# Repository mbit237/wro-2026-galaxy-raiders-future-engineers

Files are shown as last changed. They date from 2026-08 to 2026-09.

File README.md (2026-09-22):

# WRO Future Engineers 2026 - Galaxy Raiders 

## Content 

- [Team](#Team)

- [Game Rules](#2026-WRO-Future-Engineers-Game-Rules)

- [Hardware documentation](schemes/README.md)

- [Software documentation](src/README.md)

- [Models](models/README.md)

- [Video](video/video.md)

## Team 

- Henry
- Xin Yu
- Joshua

## 2026 WRO Future Engineers Game Rules

Details of the rules and challenge can be found at this link: [2026 WRO Future Engineers Game Rules](https://wro-association.org/wp-content/uploads/WRO-2026-Future-Engineers-Self-Driving-Cars-General-Rules.pdf)

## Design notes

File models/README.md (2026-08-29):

# Modelling Documentation

## The Base

As compared to last year's design, we have reduced the length significantly from 250mm to 160mm by rearranging and modifying the components to be more space efficient. The width of the base plate has also been shrunk from 134mm to 100mm. This has benefitted us greatly as the bot now has a smaller turning radius which makes its turning sharper and more responsive.

### Base Plate

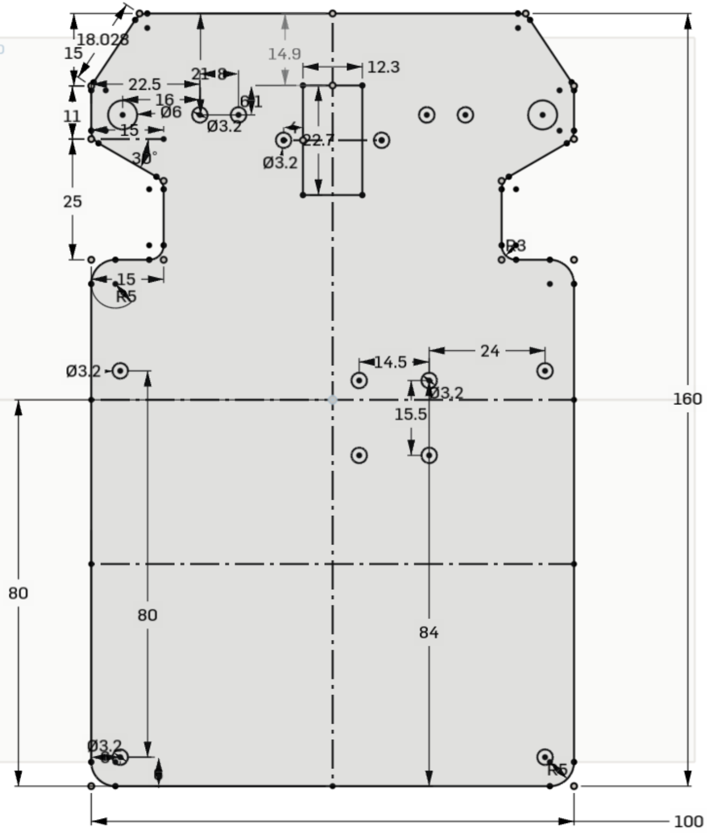
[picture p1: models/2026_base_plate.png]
base_plate


We have rearranged the motor such that it is now parallel to the wheel shaft, allowing the robot to be much shorter than the previous iteration. We also had to redesign the Ackermann steering to accommodate to the change in the base length. There are also corner cuts at the front of the base so that it does not get in the way of the wheels when steering.

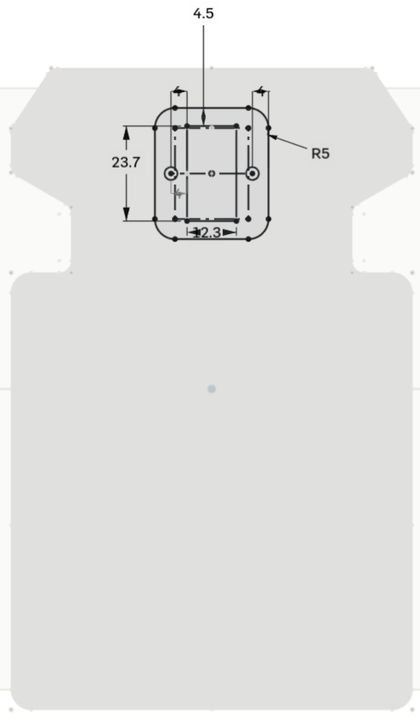
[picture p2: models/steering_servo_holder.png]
steering_servo_holder


This part is designed to sandwich the servo against the base plate, ensuring that the servo motor is secured in position.

### Level Plate

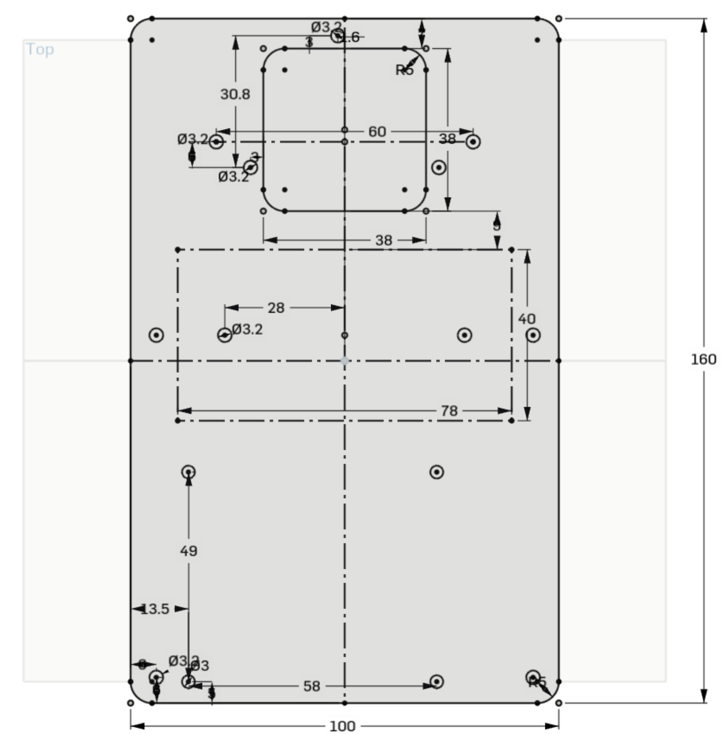
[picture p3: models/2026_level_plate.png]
level_plate


The components on the level plate has also been arranged in a much more compact manner. The main change we have made shrinking the size of the PCB, which had a lot of empty space previously. This was done by shifting the positions of the components of the PCB, reducing the amount of unoccupied space. 

### Ackermann Steering

<table>
  <tr>
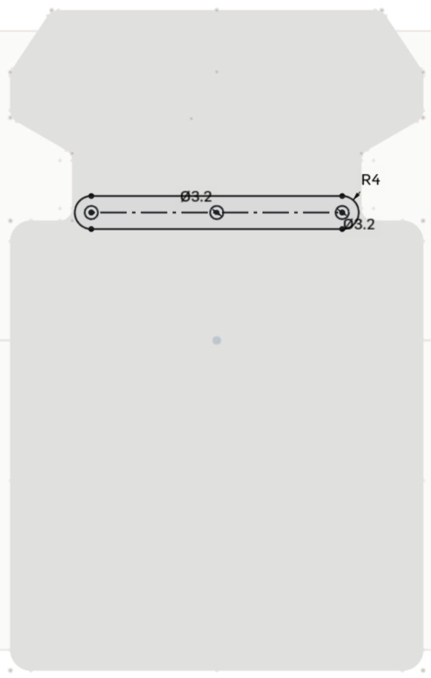
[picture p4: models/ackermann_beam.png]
ackermann_beam
    <td></td>
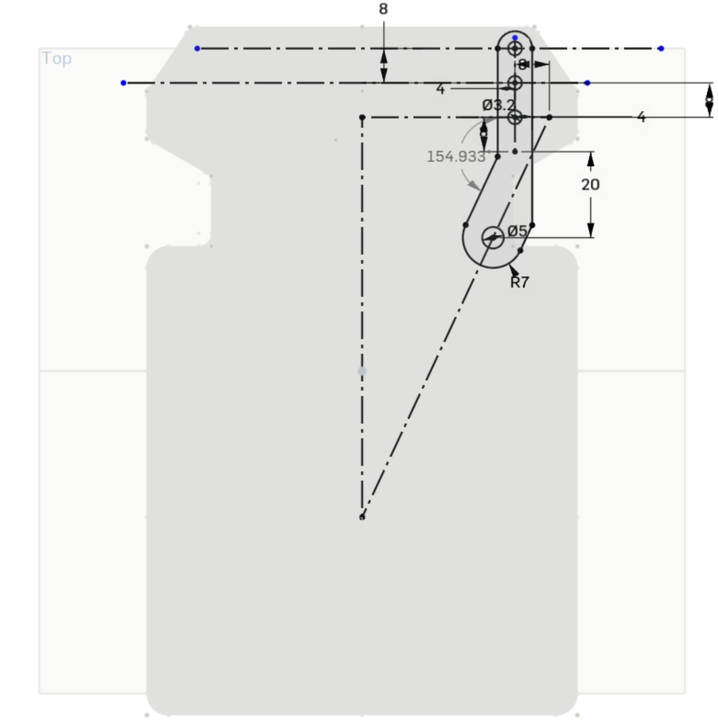
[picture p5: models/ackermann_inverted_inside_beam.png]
ackermann_inverted_inside_beam
    <td></td>
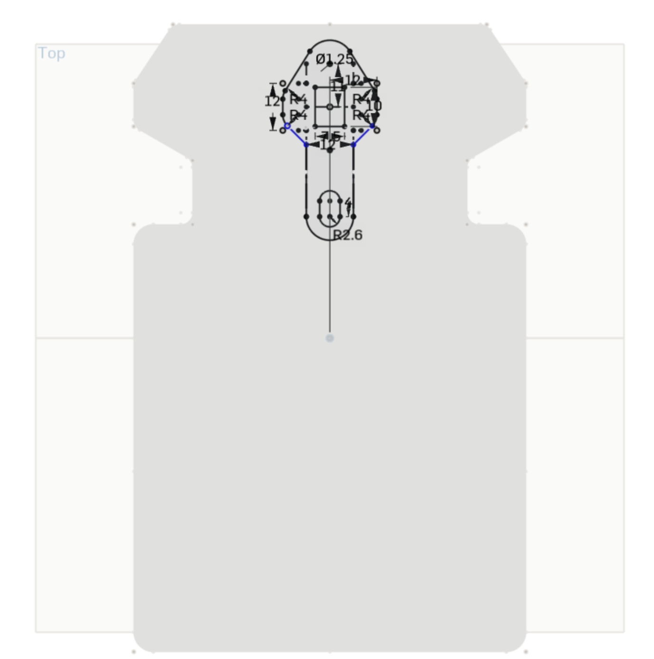
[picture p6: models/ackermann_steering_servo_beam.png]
ackermann_steering_servo_beam
    <td></td>
  </tr>
</table>

<!-- ![ackermann_beam](ackermann_beam.png), [ackermann_inverted_inside_beam](ackermann_inverted_inside_beam.png), [ackermann_steering_servo_beam](ackermann_steering_servo_beam.png) -->

The Ackermann steering mainly uses 3 parts, the steering arms, which are connected to each wheel, a servo beam, which connects to a servo motor driving the mechanismI, and a longer beam linking the steering arms and servo beam together. In order to calculate the dimensions of the Ackermann steering geometry, we sketched it out in the CAD software before laser cutting the parts, ensuring that each component was of the exact dimensions.

### Camera 

<table>
  <tr>
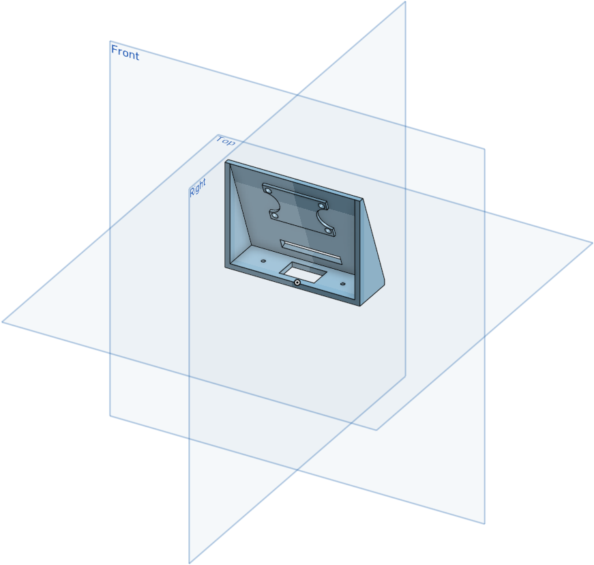
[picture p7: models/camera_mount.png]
ackcamera_mountermann_beam
    <td></td>
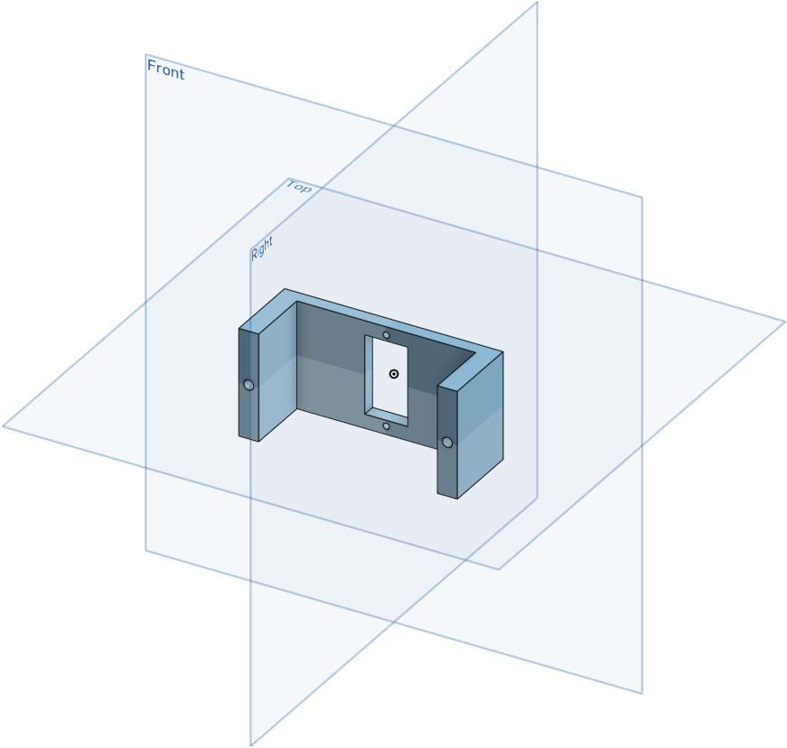
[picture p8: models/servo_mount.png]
servo_mount
    <td></td>
  </tr>
</table>

<!-- ![camera_mount](camera_mount.png), ![servo_mount](servo_mount.png) -->

The current version of our bot features a swiveling camera, which replaces the wide-angle camera found in the previous version. Although the field of view is only 60 degrees, as compared to the 120 degrees of the wide-angle lens, the servo attached to the camera allows it to swivel and face the obstacles, mitigating the problem of not being able to see the obstacle past a certain point.

### Raspbery Pi standoff

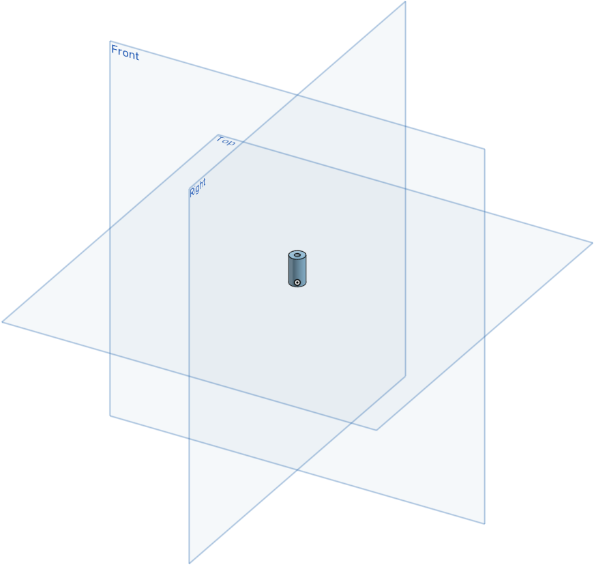
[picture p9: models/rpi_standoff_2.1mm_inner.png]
rpi_standoff


We also 3D printed a standoff to support the PCB as it was connected to the Raspberry Pi in such a way that it would be slighty tilted without the standoff.

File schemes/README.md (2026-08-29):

# Schemes
## Assembly
Our robot consists of 2 layers of components. From the 2025 competition, we continued with the idea of making use of our vertical space to mount all our components. This is achieved by splitting our robot into **different layers**. 
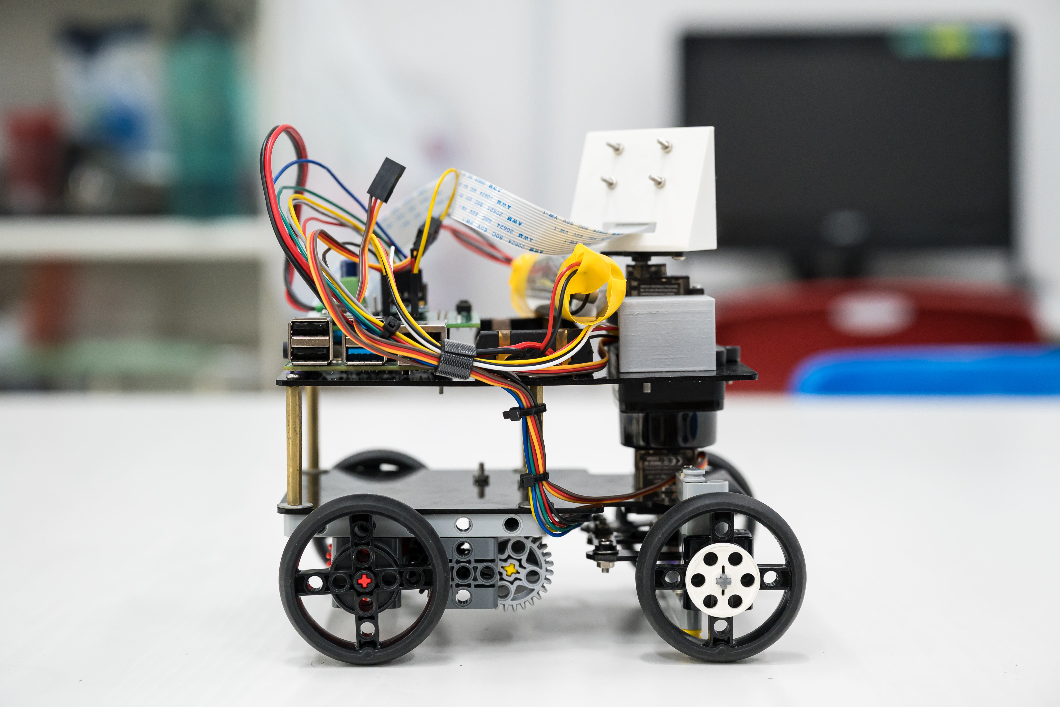
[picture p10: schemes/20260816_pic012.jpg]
robot_side_view


The **underface of the bottom layer** of our robot comprises of all our main drivebase components. This includes our Ackermann Steering Mechanism, and our Rear Wheel Drive mechanism, both of which are explained in more detail under the Mechanical Designs of this README file. The upperface of our bottom layer is not used.
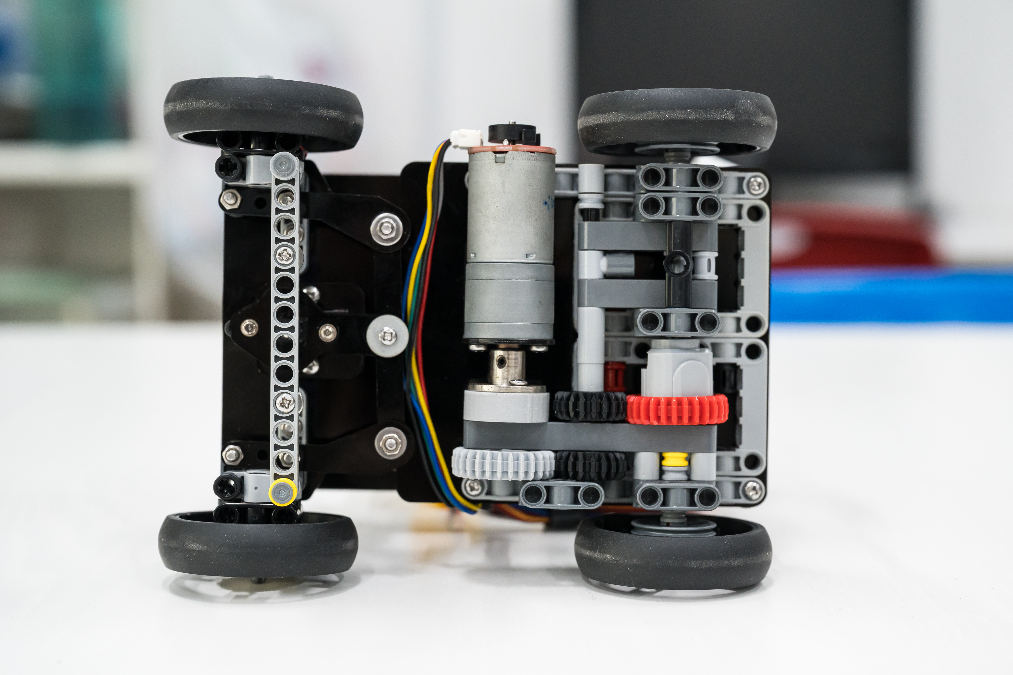
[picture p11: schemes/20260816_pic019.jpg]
robot_bottom_view


On our second/top layer, we utilise both the **underface** and the **upperface** of this layer for our robot components. 

On the **upperface**, we mounted components such as our Raspberry Pi Controller module, our PCB that is directly attached to our Raspberry Pi, a battery holder, and our rotating Camera mount. Mounting these components came with several issues, as there were several considerations when mounting each component. One of the most significant considerations we had to take into account was the importance of balancing our centre of gravity. In terms of our left-right centre of gravity, our drivebase motor on the bottom layer is mounted with a slight offset to the left. As such, we had to mount the components on our top layer to cancel out this offset. 
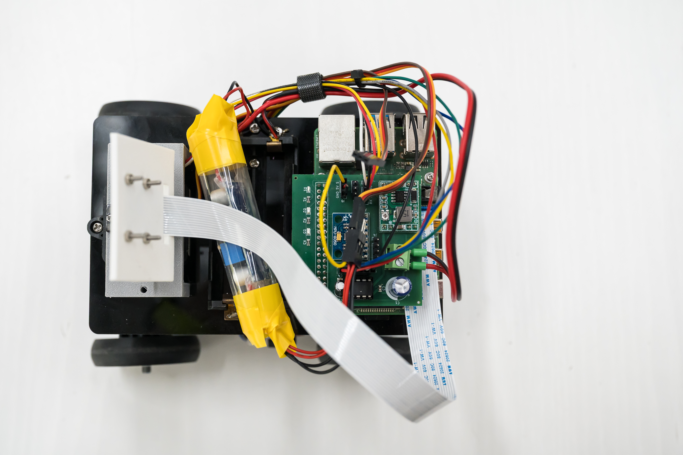
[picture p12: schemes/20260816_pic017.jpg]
robot_top_view


On the **underface of our second/top layer**, is where we mounted our Coin-D4 LiDar sensor. This is because both our layers are connected together by a long standoff, creating a large amount of empty space between both layers that allows the LiDar to capture the most readings. In this way, the only slight blindspots for our LiDar would be in the location and direction of the 4 standoffs connecting the two layers of our robot together. However, these blindspots are insignificant and almost negligible. In addition, with these standoffs in place, it acts as a pillar where we can fasten our long and stray wires to, so as to prevent the wires from being an obstruction to our LiDar and influencing our readings. In particular, the wires from the motor of our drivebase had to be routed upwards to connect to the PCB on the top layer of our robot. 
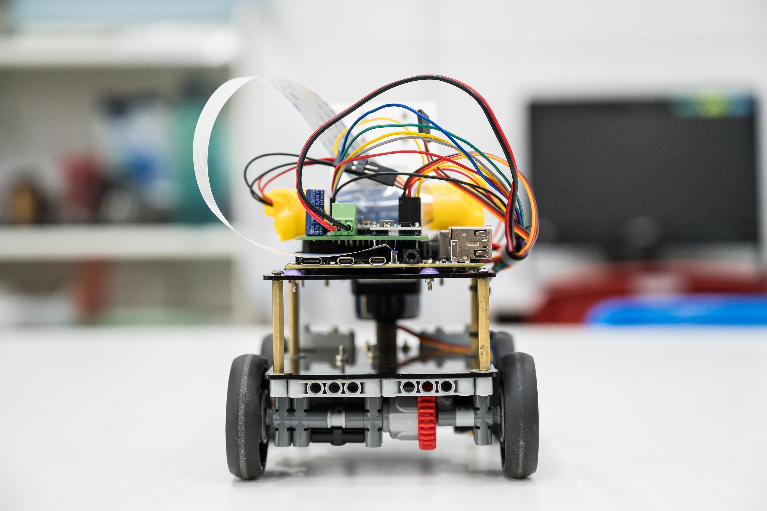
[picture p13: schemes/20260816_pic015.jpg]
robot_back_view


## Sensors
### Lidar
A **Lidar sensor** uses laser beams and speed of light to measure the distance in front of the sensor, and is useful for 2D mapping, as it provides accurate readings/measurements from any angle. The model of the Lidar sensor we are using is the **COIN-D4**, a compact, 360-degree coaxial laser scanner developed by Guoke Optical Core. It provides high-frequency distance measuring between 0.05 to 12 meters. 
CoinD4

### IMU (Gyro)
a **Gyro** allows us to measure rotation around different axes(x, y and z), allowing us to find our direction of rotation and rotation angle for our robot. By using a gyro, we can be more reliable and accurate at measuring rotation over a short period of run time. The Gyro component we are using is the **MPU-6050**, a 6-axis Inertial Measurement Unit (IMU), that combines a 3-axis gyroscope to measure rotational speed or twist, and a 3-axis accelerometer to measure gravity and linear acceleration. The built in I2C protocol allows us to communicate with this IMU sensor through our Raspberry Pi microcontroller. 
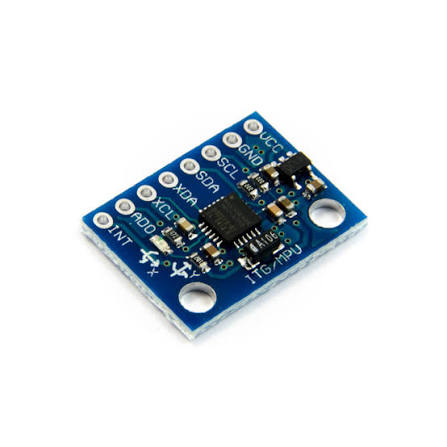
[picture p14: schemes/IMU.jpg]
IMU


### Motor Encoder
A **motor encoder** is a sensor that tracks a motor shaft's rotation and converts it into electrical signals for our Raspberry Pi. Its main purpose is to provide real-time feedback on position, speed, and direction of our drive motor. The Motor Encoder we have used for our robot is an **AB Hall-effect Encoder**, which is a type of quadrature encoder that measures rotation using the strength of the magnetic field in the x and y direction, and measures the positive/negative magnetic charge in those directions. 
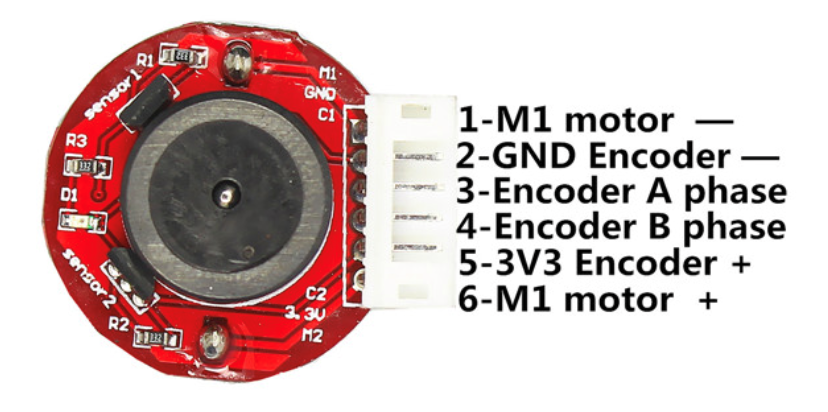
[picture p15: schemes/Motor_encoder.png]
Motor_encoder


### Motor Driver
A **motor driver** serves to regulate, direct, and coordinate the electrical energy supplied to our motor. The motor driver we have implemented on our robot is the **TA6586**, a monolithic, bidirectional H-bridge motor driver IC that uses sign-magnitude drive. In sign-magnitude control, the sign determines the motor's direction, while the magnitude determines how strongly the motor is driven. 

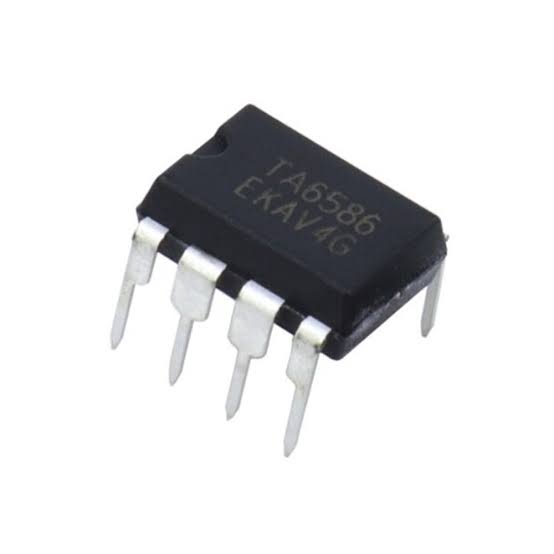
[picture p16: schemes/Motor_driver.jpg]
Motor_driver


### Camera
The **camera** lets us capture real-time footage of the Future Engineer Field while the robot is moving. This camera mainly serves to detect the red and green obstacles, allowing our robot to make the appropriate movement adjustments accordingly. The camera we have used for our robot is the **Raspberry Pi Camera Module v2**, an official 8-megapixel small add-on board with a Sony IMX219 CMOS image sensor, designed to plug directly into the CSI port of our Raspberry Pi.
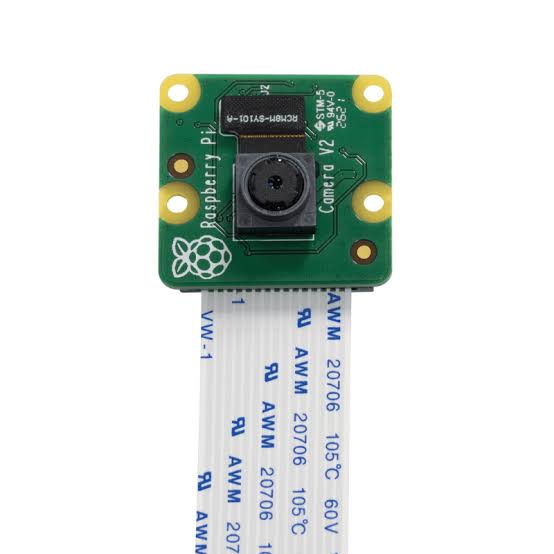
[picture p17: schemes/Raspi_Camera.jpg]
Raspi_Camera


## 3D Printed Parts
For every component that we wanted to design ourselves, we went through the same process for every part. We firstly had to figure out the functionality of said component, followed by the restrictions for the part, including size limitations, surrounding components, etc, before figuring out and taking suitable measurements for the mounting location of the part. 

To see the full designing process of each 3D printed component of our robot, please refer to the README file document in our models folder. 

## Mechanical Designs

### Drive Module
For the driving of our robot, we used a **Rear-Wheel-Drive (RWD) structure**. This structure consists of one motor, driving a central shaft that is linked to the main Differential gear, that drives two shafts on either ends of the gearbox as the outputs. Our wheels are then mounted on both shafts. For our robot in particular, our RWD structure is more unique. Our motor that drives the gearbox is not linked directly to the shaft, but mounted sideways instead to save space. By linking the motor shaft to the gearbox through gears on the side, it allows our RWD to achieve the same results, while reducing the size of our drivebase. 
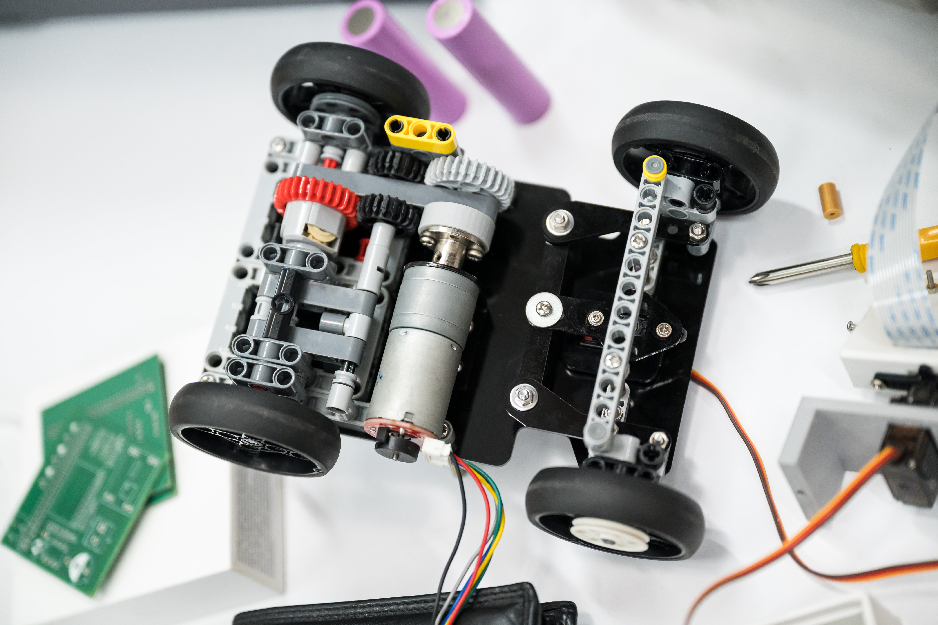
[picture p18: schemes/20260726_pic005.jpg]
drive_base


### Steering
For our steering, we referenced the popular **Ackermann Steering geometry**, that is often used in cars, vehicles etc. The Ackermann Steering geometry consists of a system of linkages on a vehicle's steering that makes the inner front wheel turn at a sharper angle than the outer front wheel in a turn, so that both steering wheels point to a common turning center. This is achieved by designing a custom Ackermann Steering linkage that connects our steering servo motor to our wheel components. To see the full designing process of this Ackermann linkage, do refer to the README file in our models folder.
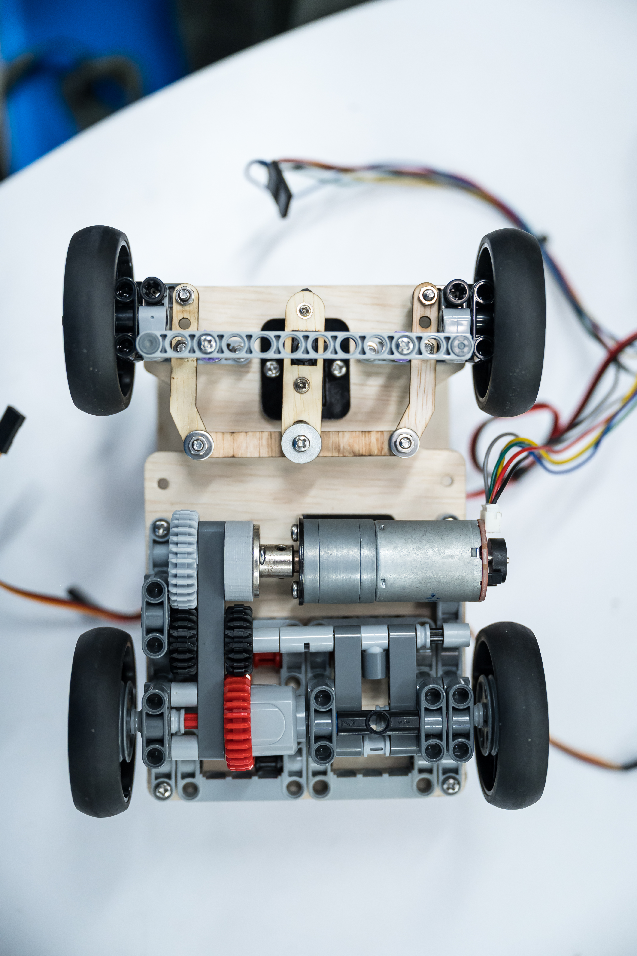
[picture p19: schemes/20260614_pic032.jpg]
Ackermann_Steering


### Camera Rotation
In the 2025 Future Engineers competition, our camera often failed to detect obstacles near the edge of the camera's POV. As such, we wanted to improve our camera mount, instead of just being a fixed stationery mount, to be able to **rotate** and check for obstacles from **different angles** quickly. This mechanism was fairly straightforward and simple, as it merely required us to mount the camera on a servo motor. We achieved this by designing a custom elevation bracket with a rectangular slot in the middle for the servo motor to lie in. This bracket allos the servo motor to sit above our LiDar sensor, a location we found most suitable for our camera. Thereafter, we mounted our Camera bracket to the servo motor, allowing our camera to then rotate within a range of 180 degrees. 

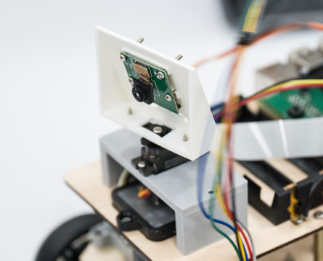
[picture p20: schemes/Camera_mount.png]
Camera_rotation


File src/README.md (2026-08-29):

# Software Documentation 

## General Approach (applied to both open and obstacle challenge)

1. [Odometry](#odometry): Estimating pose using [encoder](#encoder---ab-hall-effect-encoder) and [gyro](#gyro---mpu-6050)
2. [Localisation](#localisation) using LiDAR using [Iterative Closest Points](#iterative-closest-point) (previously [Spike Landmark](#spike-landmark)) before merging both the odometry pose and localised pose using a [complementary filter](#complementary-filter)
3. [Path following](#path-following) using the new merged pose 

## Sensor Libraries 

### LiDAR - COIN-D4 

We created our own library, because there weren't any python raspberrypi libraries, to receive data from the COIN-D4 LiDAR which uses the UART protocol. To create it, we used the serial package to open the serial port /dev/ttyS0 with the baud rate 230400.  

Everytime the input buffer is populated, we check if the first two character matches the data header '\xAA\x55' before retrieving the sample count (4th byte) so that every group of readings is fully taken before being checking the checksum and parsing it. The scan frequency is roughly 10 rotations per second and each frame of data points is 360 degrees.  

Afterwards, each reading is assigned to the closest angle it was taken from, by rounding the angle and taking a modulus of 360 as the index. 

### Gyro - MPU-6050 

The gyro sensor uses the i2c protocol so initially, we used the pigpio library to receive data, but realised it was too slow and caused significant delays, so we switched to smbus. 

Additionally, we had to numerical integrate the z-axis gyroscope data over time to calculate the heading:
1. Read the raw angular velocity
2. Subtract the calibrated gyro offset value
3. Calculate the time passed since the previous reading
4. Take the sum of the current and previous z readings, multiply it by the time passed, and divide it by the sensitivity scale factor (131 * 2)

To find the calibrated gyro offset value, we also created a calibration function so that when we leave the robot as stationary, we can take the average of 500 measurements (which are suppose to be zero values) to find the z error. We also created functions to save the calibration as a txt file and load it. 

### Encoder - AB Hall-effect Encoder 

It is a type of quadrature encoder that measures rotation using the strength of the magnetic field in the x and y direction, and measures the positive/negative magnetic charge in those directionn. The true mechanical angle is then recovered by applying arctangent because the rotating magnet produces orthogonal sine and cosine magnetic field components. 

We used the pigpio library and programmed two callback functions to detect change in states for each channel A (Pin 5) and B (Pin 6)

```python 
cb1 = pi.callback(5, pigpio.RISING_EDGE, self.step_count)
cb2 = pi.callback(6, pigpio.EITHER_EDGE, self.drive_dir)
```

In the first callback, when channel A rises, it checks the state of channel B. If B is high, it is moving backward, whereas if B is low, it is moving in the opposite direction, forward. The second callback is constantly updating the state of channel B. 

Encoder calibration:
2025
1st attempt
- 1522.4mm – 5113 steps, 0.298mm  – 1 step 
2nd attempt
- 4670 mm – 15795 steps, 0.296mm – 1 step

2026
| Actual | Encoder | Time | Notes |
| -----: | ---: | ---: | --- |
| 1285 | 2705 |  5 s | |
| 2005 | 4370 |  8 s | Discarded |
| 2075 | 4365 |  8 s | |
| 2070 | 4357 |  8 s | |

### Motor Driver - TA6586

The TA6586 is a monolithic, bidirectional H-bridge motor driver IC that uses sign-magnitude drive. In sign-magnitude control, the sign determines the motor's direction, while the magnitude determines how strongly the motor is driven. In the library, the sign of the speed argument selects the direction of rotation, while the absolute value of speed determines the PWM duty cycle and by extension the motor speed.

For positive speed, the GPIO pins 20, 21 are configured as such
```python
self.pi.set_PWM_dutycycle(21, 255-speed) # PWM controlled
self.pi.set_PWM_dutycycle(20, 255) # constantly high 
```
vice versa for negative speed
```python
self.pi.set_PWM_dutycycle(21, 255) # constantly high 
self.pi.set_PWM_dutycycle(20, 255+speed) # PWM controlled 
```

This allows for lower switching losses because fewer transistors switch simultaneously 

### Camera - Raspberry Pi Camera Module v2

We use the Raspberry Pi Camera Module with the picamera2 library to identify the colour of the obstacle in front of the car.
The colour detection works as follows:
1. Remove the top 105 pixels from the image to prevent the camera from seeing over the wall, avoiding any false positives
2. Apply a gaussian blur on the image to remove noise and small variations in the image
3. Convert the image from BGR to HSV. HSV is more useful in this case as it separates the hue from the brightness of colours, making it more reliable under different lighting conditions
4. Using cv2.inRange(), a binary mask is applied to the image, where the white parts of the image represent the areas that are within the tested thresholds for green and red obstacles.
5. Run cv2.SimpleBlobDetector() on the binary masks. It rejects blobs that are smaller than 650 pixels to remove any noise

For each colour, detect_blob() will only return the largest blob that it detects.

### Servos (Camera Swivel, Steering) - MG90

To calibrate the servos, we tested with different values from 500 to 2500 microseconds (µs) to find the centre, maximum and minimum. 

| Servo | Centre | Max, Min (in degrees) | 
| -----: | ---: | ---: |
| Camera | 1475 |  87 |
| Steering | 1425 |  42 |

### I/O Interface (Button, LEDs)

In total, we have a button to start and stop the programme and three LEDS (red, yellow, green) to signal different messages for different challenges: open (red -- stationary, green -- running), obstacle (yellow -- stationary, green -- sees green obstacle, red -- sees red obstacle). 

## Localisation 

### Odometry 

We use the wheel rotation and gyro to estimate the robot's pose (position and heading) while it is running. 

- steer_in_dir(): steering (proportional control) 
- augment_path(), augment_paths(): Steering back to line 
    - Find path vector = (x2-x1) / (y2-y1)
    - Find distance of path
    - Find path vector in units
    - Find perpendicular path vector
    - Find path direction 
- dot(): dot product 
    - how far robot is off the path – drive_path()
    - how far robot has traveled along the path 
- drive_path(), drive_paths():

- estimate_pose():
    - First version: looked at the heading and assumed a straight path based on the heading 

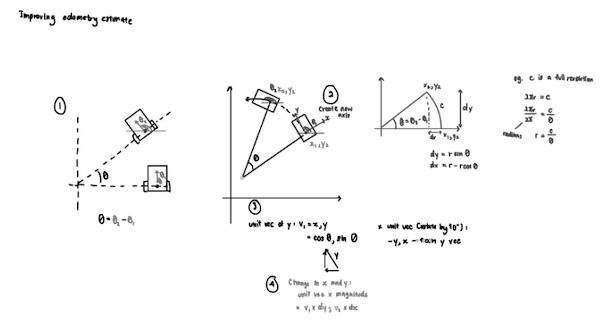
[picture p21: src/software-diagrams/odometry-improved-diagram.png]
odometry-improved-diagram
    

    - Second version: treat the movement as an arc of a circle
        - Treat the centre of rotation as the origin, which means $\theta = \theta_{2} - \theta_{1}$, to find the local $d_x, d_y$
        $$d_y = r sin \theta, d_x = r cos \theta$$
        - Since $r = \frac{c}{\theta}$, in which c is the distance travelled
        $$d_y = \frac{c}{\theta} sin \theta, d_x = \frac{c}{\theta} cos \theta$$
        - To apply this back to the original axis, we take the x, y vectors of the "morphed" graph, (rotate y vector by $90^o$), before we multiply the unit vectors with the local $d_x, d_y$ to find the global $d_x, d_y$
        $$y^′=(cosθ, sinθ)$$
        $$x^′=(−sinθ, cosθ)$$
        $$d_X = x^′ \times d_x, d_Y = y^′ \times d_y$$

Afterwards, we integrate other localisation methods on top of using odometry, by using a complementary filter. 

### Spike Landmark 

Initially, we used the spike landmark method during the 2025 season of WRO, but we wanted to improve our localisation method so we have since shifted to the [Iterative Closest Point](#Iterative-Closest-Point) method. 

Essentially, the method identifies which lidar readings are spikes or points of interest, in our case corners which are noticeably further away than the adjacent readings. Afterwards, we calculate if there is any difference between the supposed and actual cartesian coordinate of the landmark to find the error. 

- Defined 8 landmarks: 4 inner corners, 4 outer corners, marked as green circles
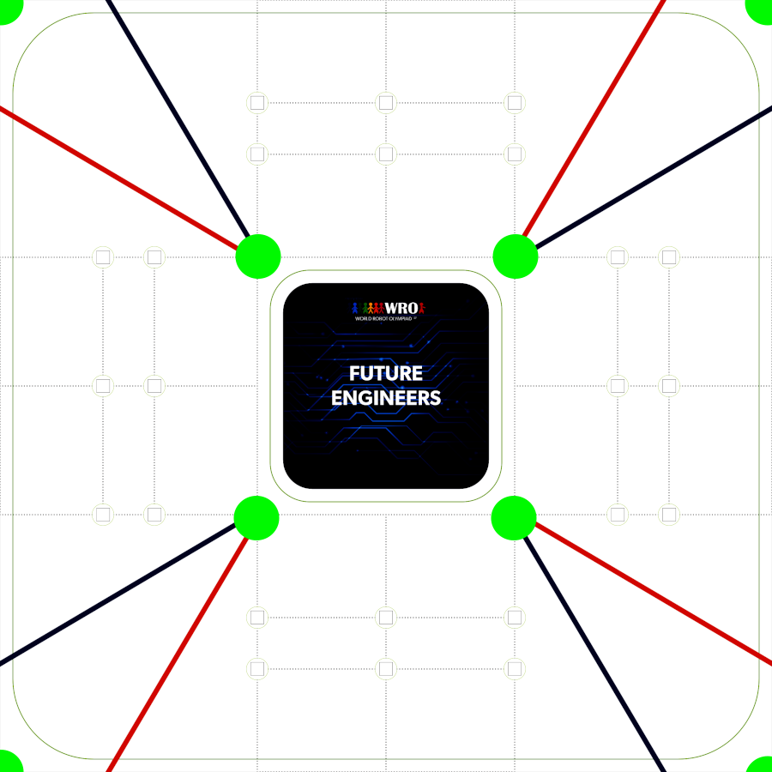
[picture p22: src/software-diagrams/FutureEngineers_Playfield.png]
future-engineers-playfield

- add_cartesian(): convert lidar readings into cartesian coordinates
- identify_spikes()  
	- the different between two lidar measurements adjacent to the centre measurement have to show a significant difference
	- filter out spikes within 250mm
- match_landmarks(): within 120mm, which we tested as the most optimal threshold 
- calc_position_error(), calc_angle_error(): according to the spikes matched, we calculate the total error accumulated for x, y and heading (angle of the spike from the robot) separeately before finding the average for each value and adding it to the odometry_pose 

However, this method only uses a few points out of the approximate 400 we get from the lidar in comparison to the [Iterative Closest Point](#Iterative-Closest-Point) method that makes full use of all the lidar readings. 

### Iterative Closest Point 

- augment_walls(): Define the 8 walls on the playfield, getting their path vector, path direction, unit path vector and perpendicular path vector which are values needed 
- add_cartesians(): same as the one used in the Spike Landmark 

**localise():**
Let's start by transforming 1 point on a cartesian plane. 

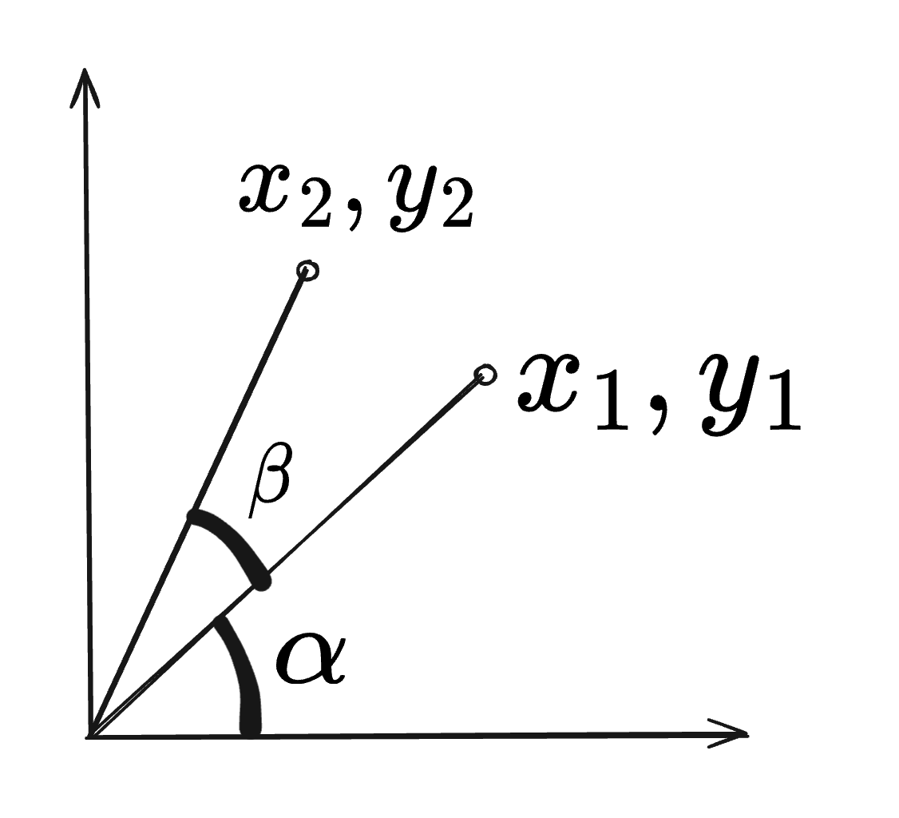
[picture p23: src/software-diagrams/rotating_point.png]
rotating-a-point


To handle the rotation, we can 

$$x_2 = R \cos(\alpha + \beta) = R [\cos(\alpha)\cos(\beta) - \sin(\alpha)\sin(\beta)]$$
$$y_2 = R \sin(\alpha + \beta) = R [\sin(\alpha)\cos(\beta) + \cos(\alpha)\sin(\beta)] $$

Substitute $$x_1 = R \cos(\alpha), y_1 = R \sin(\alpha)$$, 

$$x_2 = x_1\cos(\beta) - y_1\sin(\beta) $$
$$y_2 = y_1\cos(\beta) + x_1\sin(\beta) $$

Since the change in x, y and heading is going to small as the frequency of the Coin-D4 is 10 Hertz, we can linearize the functions, by taking their gradients near 0. 

$$ \cos(\beta) \approx 1, \sin(\beta) \approx \beta $$

$$ \therefore x_2 = x_1 - y_1(\beta), y_2 = y_1 + x_1(\beta) $$

Afterwards, we add translation as $T_x, T_y$

$$ x_2 = x_1 - y_1(\beta) + T_x, y_2 = y_1 + x_1(\beta) + T_y $$
$$ \therefore x_2 - x_1 = -y_1(\beta) + T_x, y_2 - y_1 = x_1(\beta) + T_y $$

When we put it in a matrix form, 

$$ \begin{bmatrix} 
-y_1 & 1 & 0 \\
x_1 & 0 & 1 
\end{bmatrix}
\begin{bmatrix} 
\theta \\
T_x \\
T_y
\end{bmatrix} = \begin{bmatrix} 
x_2 - x_1 \\
y_2 - y_1
\end{bmatrix}
$$

And we can add as many points as we want to the equation

$$ \begin{bmatrix} 
-y_1 & 1 & 0 \\
x_1 & 0 & 1 \\
\vdots & \vdots & \vdots
\end{bmatrix}\begin{bmatrix} 
\theta \\
T_x \\
T_y
\end{bmatrix} = \begin{bmatrix} 
x_2 - x_1 \\
y_2 - y_1 \\
\vdots
\end{bmatrix}
$$ 

To solve this $Ax = B$, we take the psuedoinverse of A multipled by B, $x = A^{-1} B$ which we calculate using the `numpy` library. 

Now that we have the transformation matrix, we need to identify which point on the wall does the lidar reading correspond to, in our case we find the shortest perpendicular distance between each wall and the reading. 

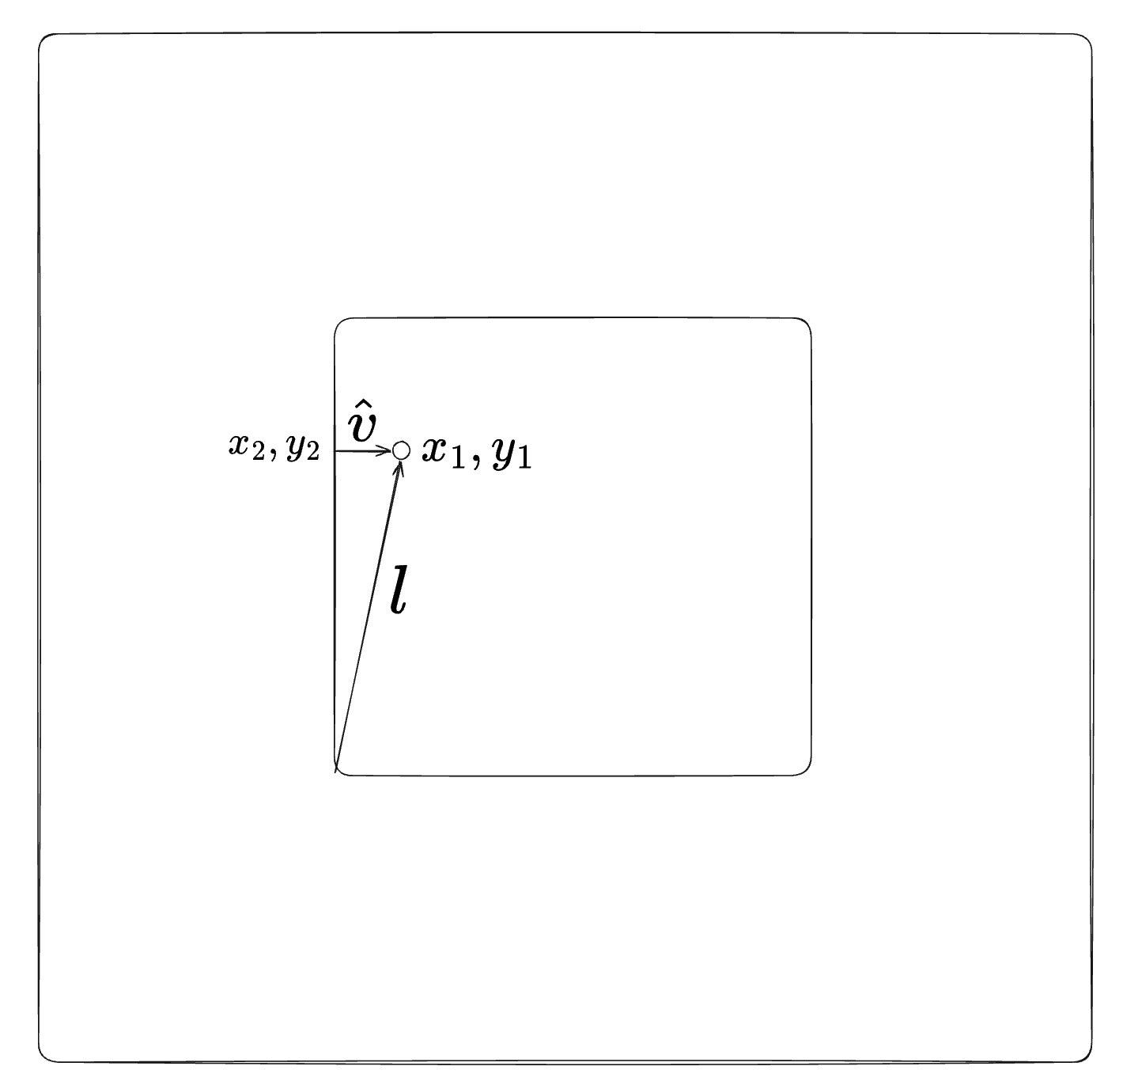
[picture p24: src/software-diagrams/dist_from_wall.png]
dist_from_path


$dist = \hat{v} \cdot l$, in which $l$, is the vector of the lidar reading from the start of the wall. If it is a vertical wall, we only solve for the x-value and vice versa for a horizontal wall. 

**localise_iter():**
Since we are dealing with an overdetermined system, there is no exact solution, but only a rough estimate. Running it with more iterations will help minimise the errors. 

We tested it with a set of fake data which started with the mini-sets contain that have far fewer readings, before moving on to [set 1](/point_cloud_test_sets/set1.txt) which has 360 points, closer to what we will expect in the acutal run. After debugging, we realised that it was able to get close to the actual pose with only one iteration. Additionally, we timed it and it took roughly $\frac{1}{50}$th of a second, meaning it is able to keep up with the lidar which takes 10 readings every 1 second. 

### Complementary Filter

We set very small values for the localisation pose because we found that the odoemetry pose was already quite accurate. 
```
POSITION_FILTER_RATIO = 0.1 
HEADING_FILTER_RATIO = 0.01 
```

## Path following 

pathfollowing

- drive_path(), drive_paths(): 
	- Find the error by taking the dot product of the unit vector perpendicular to the path and the vector from the start of the path to the robot (robot_vector): perpendicular displacement $= \hat{u} \cdot \vec{r} $
	- Get the correction / perpendicular distance of the robot from the path by multiplying the error by a gain
	- Add the target_dir of the path with the correction which is what the robot will steer towards 
	- Keep checking the dist_travelled_along_path if it reaches the end by taking the dot product of the unit_path_vector and the robot vector: displacement along path $= \hat{p} \cdot \vec{r} $

Thus, the robot is able to slowly adjust itself towards the path. 

## Camera Tracking 

- Plotted points along the playfield, in between every pair of squares, where the obstacle could be placed
- Camera will track two points ahead of its current position
- Reused an existing function (dir_to_point) to calculate the angle the servo needs to turn to the obstacle, but adjusting the range to -180 to 180, as the function is used for cases where the range is 0 to 360

### Open Strategy 

During the initialisation, the robot will assume it is moving clockwise and travel the first path until it reaches the corner: this is where the robot will read the distances from lidar sensor for the points (0mm, 2700mm) and (1000mm, 2700mm). If the distance for the left point is greater than the right point, it will deduce that it is moving counterclockwise and update its pose accordingly. The reason why we chose these points instead of measuring the left and right distances is because we encountered some issues with determining the sides at certain start positions.

In the rest of the run, the robot will followed a preplanned clockwise and counterclockwise path, whihc is as close to the centre of the lanes as possible. By default, it would take the outermost path, 50 cm away from the outer wall. However, if the lidar detects that the first section of the inner wall is extended, the lane will shift closer to the wall such that it is 30 cm away from the outer wall. 

We plan on improving our strategy by adjusting the paths to the inner paths where possible. 

**Pseudocode** 

>find initial position 
>first path run to confirm pose
>main run:
>> (process described in [general approach](#general-approach-applied-to-both-open-and-obstacle-challenge))
>> if at ending position:
>>> stop 

### Obstacle Strategy 

The robot will determine its direction (clockwise or counterclockwise) by getting the front, rear and side distances because the initial position generally fixed. It will check if an obstacle is in front of it before moving back. 

In main run, the robot will switch between two fixed sets of paths, an outer and inner lane. Depending on the colour of the blocks in front, it will switch between the two paths to follow. For example, if the robot is moving clockwise, detecting a red block will cause it to follow the inner paths, and vice versa for the green blocks. This will switch if the robot is moving counterclockwise. An improvement we made since 2025 is that we implemented [camera tracking](#camera-tracking) such that the camera follows the colour of the obstacle two sections ahead which ensures that the robot never misses the obstacle. In 2025, a major issue we had is that because our robot was larger and the field of vision of the robot was wider, we had to keep readjusting our paths so that the robot would not miss the obstacles, especially at the corners. 

As of 25th August, the parking programme is still unfinished, but our strategy is to get into the exact position at the start of parking by moving the robot back and forth. As for the parallel parking procedure, it involves 

*(Scenario in which the parking area is on the right)*
- Turn right to 45, move back till vehicle is facing 45
- Turn left to 0, move back till vehicle is behind the barrier 
- Turn left to 45, move back tile vehicle is facing 0 

Reference image:
parallel parking

**Pseudocode**

>find initial position
>if obstacle in front: move back 
>main run:
>> (process described in [general approach](#general-approach-applied-to-both-open-and-obstacle-challenge))
>> if at ending position:
>>> parking

## Debugging / Telemetry tools 

To make it easier to visualise the different variables — robot pose, lidar readings, matched spikes, colour of block detected - we created a telemetry software, using sockets to transfer data from the raspberrypi (client) to a computer (server) with our own protocol. We also kep the messages short so that it all fits in one packet and is not sent too frequently. Afterwards, we used tkinter to draw out the points on the playfield with the exact values written out at the left side of the interface. 

telemetry

Additionally, we changed our intialiser.sh file for easier debugging. Now, every time we run, the programme will log the standard output and error messages to a file with the date and time. To change the mode of the robot (sleep, open, obstacle), we will create a softlink between main_obstacle/open/sleep.py to main.py.

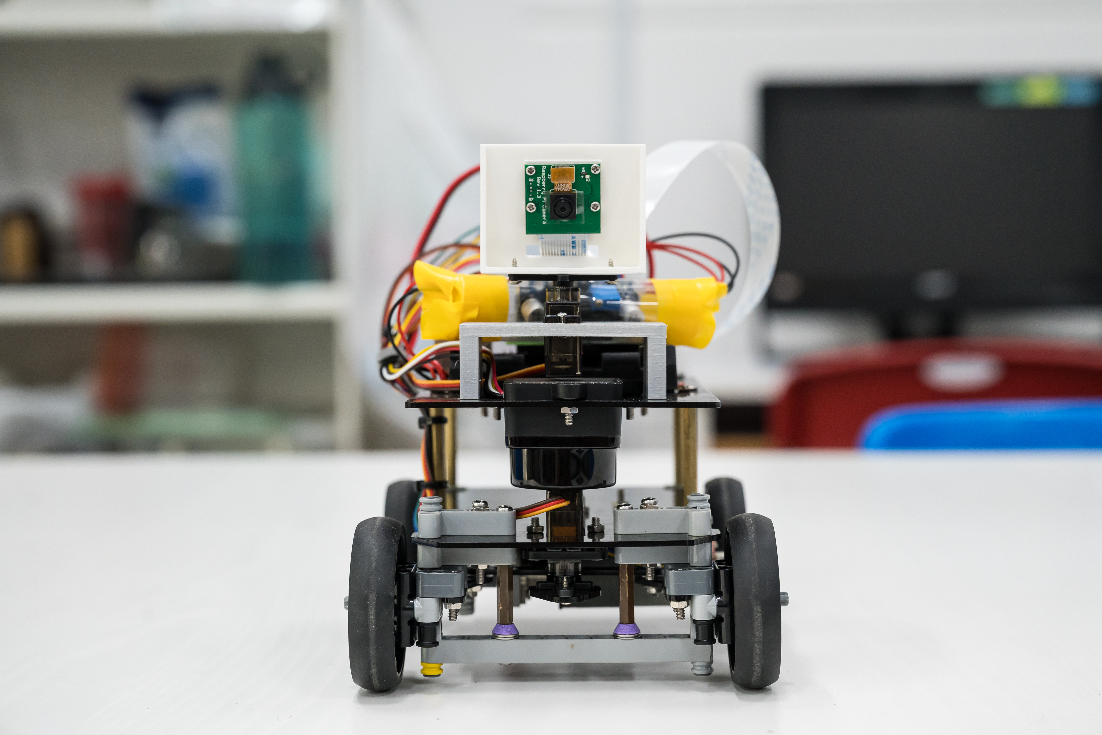
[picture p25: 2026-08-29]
v-photos/20260816_pic013.jpg

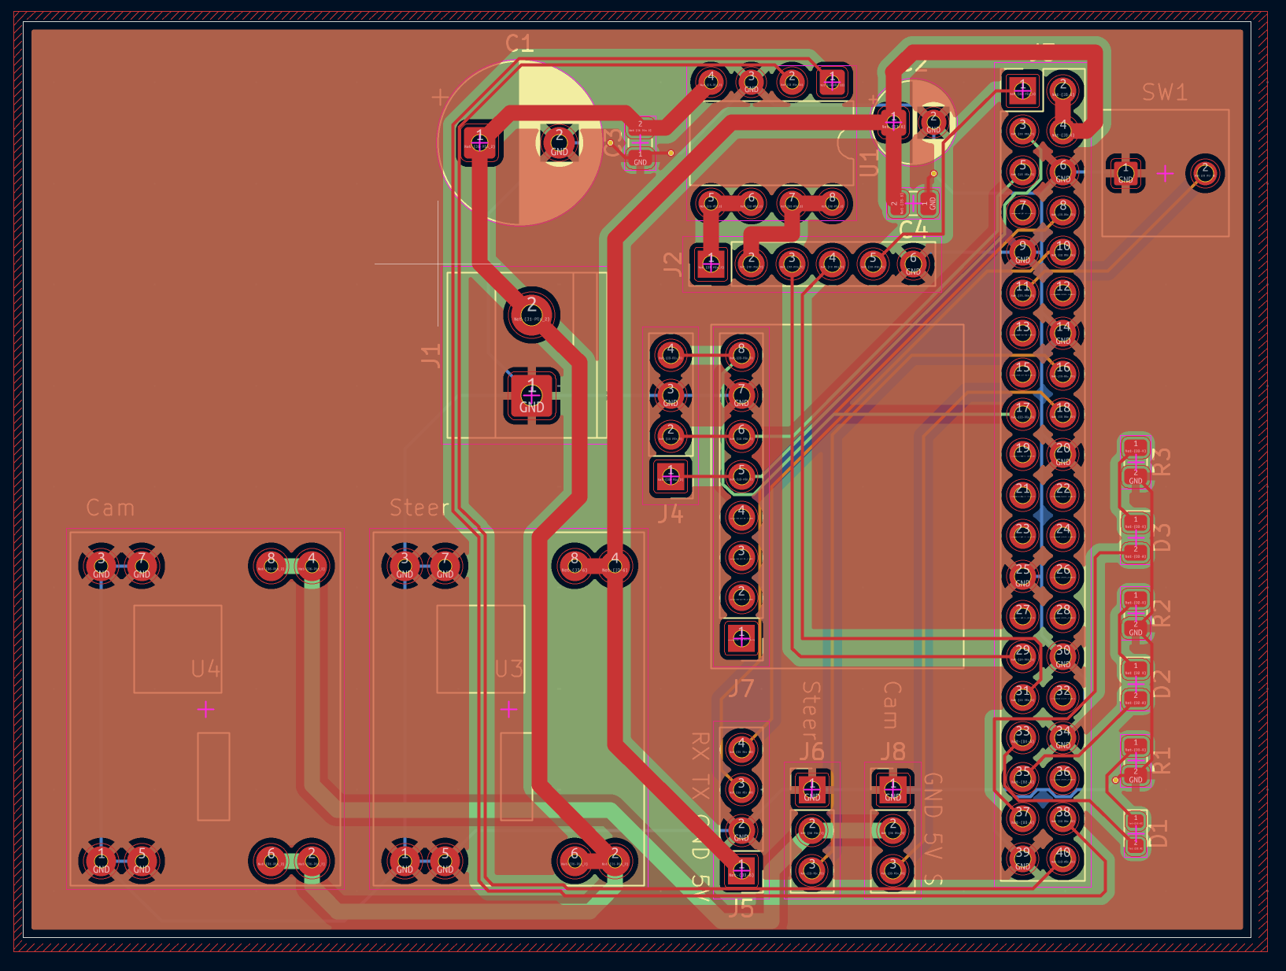
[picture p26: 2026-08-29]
schemes/Screenshot 2026-08-23 at 4.50.41 PM.png

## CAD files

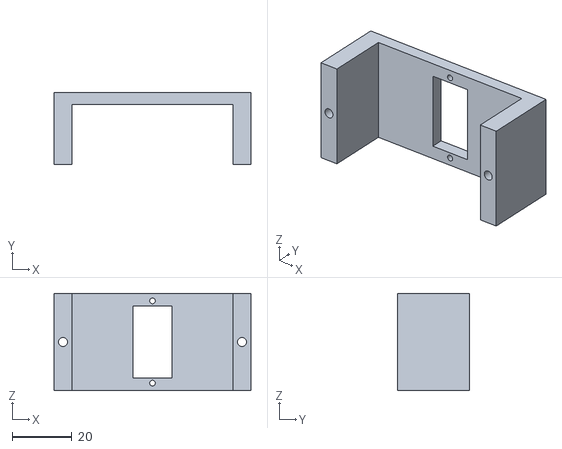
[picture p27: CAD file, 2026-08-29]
models/servo_mount.stl
66.0 x 24.0 x 32.5

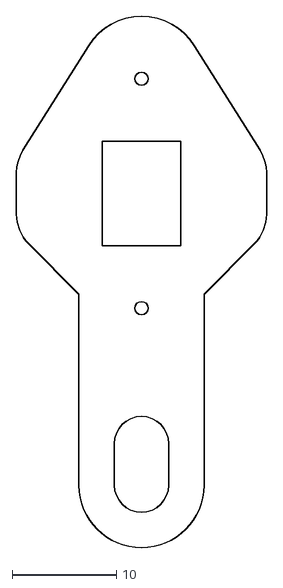
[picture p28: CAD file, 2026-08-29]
models/ackermann_steering_servo_beam.dxf
24.0 x 51.0

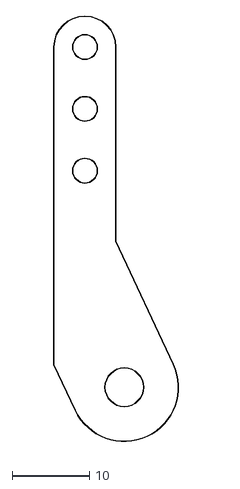
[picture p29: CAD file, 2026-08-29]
models/ackermann_inverted_inside_beam.dxf
17.1 x 56.0

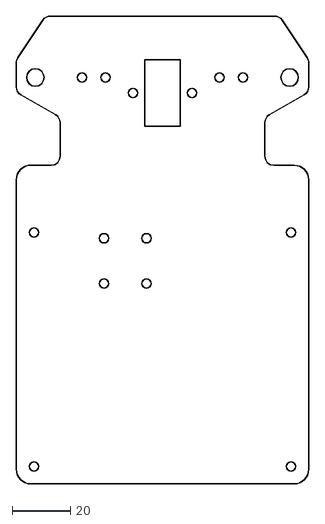
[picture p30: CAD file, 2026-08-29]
models/2026_base_plate.dxf
100.0 x 160.0

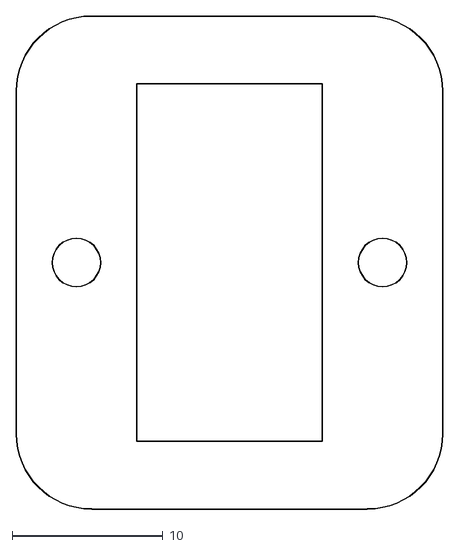
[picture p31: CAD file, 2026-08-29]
models/steering_servo_holder.dxf
28.3 x 32.7

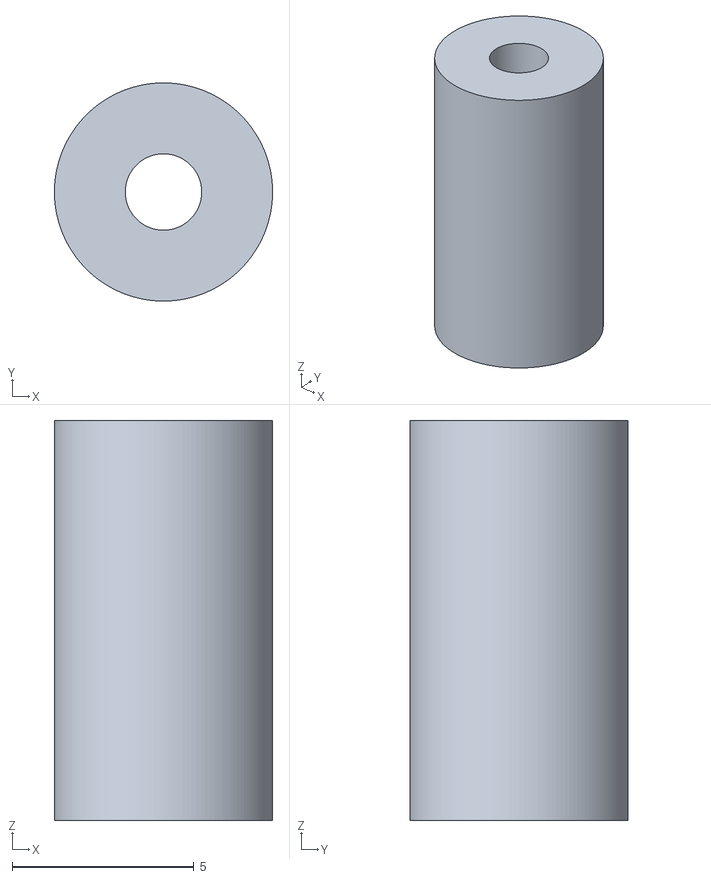
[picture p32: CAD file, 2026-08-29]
models/rpi_standoff_2.1mm_inner.stl
6.00 x 6.00 x 11.0

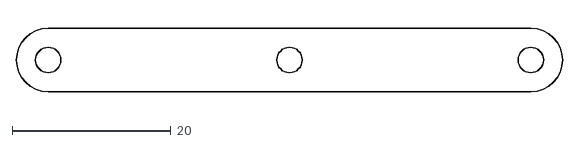
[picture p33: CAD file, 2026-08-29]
models/ackermann_beam.dxf
68.8 x 8.00

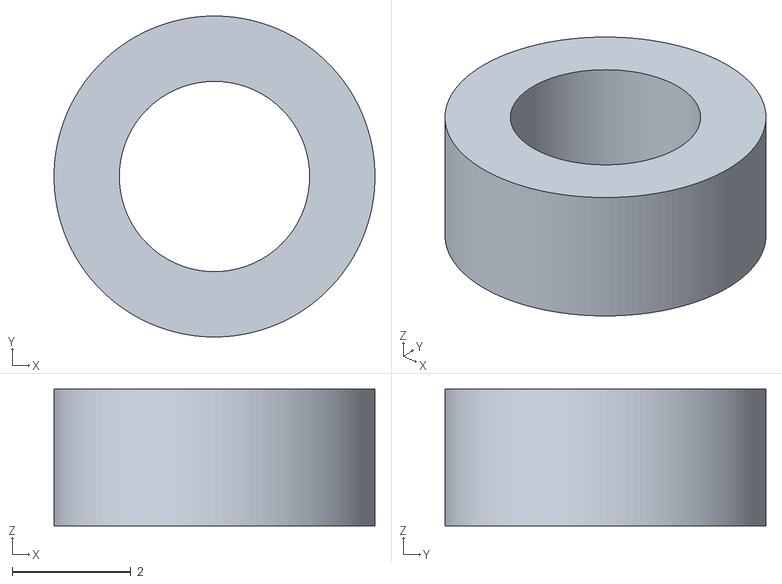
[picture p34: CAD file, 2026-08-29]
models/5.4mm_spacer.stl
5.40 x 5.40 x 2.30

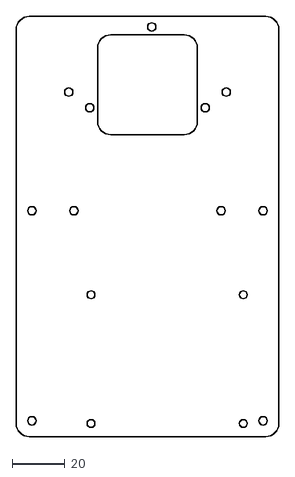
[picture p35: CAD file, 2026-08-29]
models/2026_level_plate.dxf
100.0 x 160.0

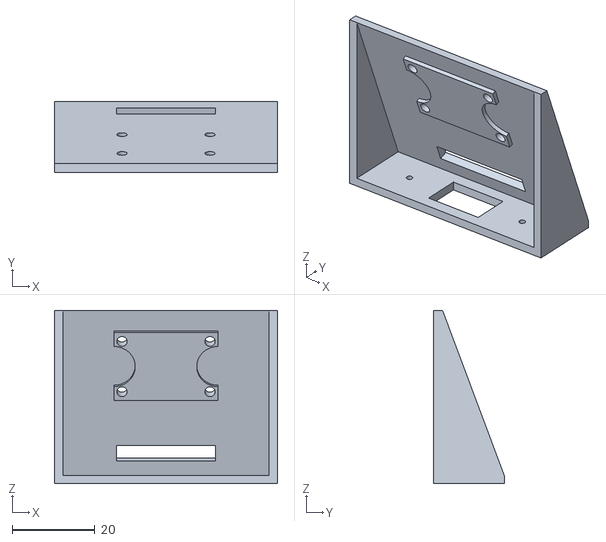
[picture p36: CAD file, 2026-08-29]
models/camera_mount.stl
54.0 x 17.1 x 42.0

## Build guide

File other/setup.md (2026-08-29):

# Setup Guide 

## Transferring files to raspberrypi 

To download all the necessary files into the raspberrypi, use the command:

```bash
scp <path>/<file_name>.py <user>@192.168.0.104:<path>>
```

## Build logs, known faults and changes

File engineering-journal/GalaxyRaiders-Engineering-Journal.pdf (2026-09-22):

# Software Documentation

# General Approach (applied to both open and

# obstacle challenge)

1. Odometry: Estimating pose using encoder and gyro
2. Localisation using LiDAR using Iterative Closest Points (previously Spike Landmark) before merging both the odometry pose and localised pose using a complementary filter
3. Path following using the new merged pose

# Sensor Libraries

## LiDAR - COIN-D4

We created our own library, because there weren't any python raspberrypi libraries, to receive data from the COIN-D4 LiDAR which uses the UART protocol. To create it, we used the serial package to open the serial port /dev/ttyS0 with the baud rate 230400.

Everytime the input buffer is populated, we check if the first two characters match the data header '\xAA\x55' before retrieving the sample count (4th byte) so that every group of readings is fully taken before checking the checksum and parsing it. The scan frequency is roughly 10 rotations per second and each frame of data points is 360 degrees.

Afterwards, each reading is assigned to the closest angle it was taken from, by rounding the angle and taking a modulus of 360 as the index.

## Gyro - MPU-6050

The gyro sensor uses the i2c protocol so initially, we used the pigpio library to receive data, but realised it was too slow and caused significant delays, so we switched to smbus.

Additionally, we had to numerical integrate the z-axis gyroscope data over time to calculate the heading:

- Read the raw angular velocity
- Subtract the calibrated gyro offset value
- Calculate the time passed since the previous reading
- Take the sum of the current and previous z readings, multiply it by the time passed, and divide it by the sensitivity scale factor (131 * 2)
- To find the calibrated gyro offset value, we also created a calibration function so that when we leave the robot as stationary, we can take the average of 500 measurements (which are supposed to be zero values) to find the z error. We also created functions to save the calibration as a txt file and load it.

## Encoder - AB Hall-effect Encoder

It is a type of quadrature encoder that measures rotation using the strength of the magnetic field in the x and y direction, and measures the positive/negative magnetic charge in those directions. The true mechanical angle is then recovered by applying arctangent because the rotating magnet produces orthogonal sine and cosine magnetic field components.

We used the pigpio library and programmed two callback functions to detect change in states for each channel A (Pin 5) and B (Pin 6)

cb1 = pi.callback(5, pigpio.RISING_EDGE, self.step_count)
cb2 = pi.callback(6, pigpio.EITHER_EDGE, self.drive_dir)
In the first callback, when channel A rises, it checks the state of channel B. If B is high, it is moving backward, whereas if B is low, it is moving in the opposite direction, forward. The second callback is constantly updating the state of channel B.

Encoder calibration:
2025
1st attempt: 1522.4mm – 5113 steps, 0.298mm – 1 step 2nd attempt: 4670 mm – 15795 steps, 0.296mm – 1 step

2026

Actual | Encoder | Time | Notes
1285 | 2705 | 5 s

2005 | 4370 | 8 s | Discarded
2075 | 4365 | 8 s
2070 | 4357 | 8 s

## Motor Driver - TA6586

The TA6586 is a monolithic, bidirectional H-bridge motor driver IC that uses sign-magnitude drive. In sign-magnitude control, the sign determines the motor's direction, while the magnitude determines how strongly the motor is driven. In the library, the sign of the speed argument selects the direction of rotation, while the absolute value of speed determines the PWM duty cycle and by extension the motor speed.

For positive speed, the GPIO pins 20, 21 are configured as such

self.pi.set_PWM_dutycycle(21, 255-speed) # PWM controlled self.pi.set_PWM_dutycycle(20, 255) # constantly high
vice versa for negative speed

self.pi.set_PWM_dutycycle(21, 255) # constantly high
self.pi.set_PWM_dutycycle(20, 255+speed) # PWM controlled
This allows for lower switching losses because fewer transistors switch simultaneously

## Camera - Raspberry Pi Camera Module v2

We use the Raspberry Pi Camera Module with the picamera2 and cv2 library to identify the colour of the obstacles in front of the cars.
The colour detection works as follows:
1. Remove the top 105 pixels from the image to prevent the camera from seeing over the wall, avoiding any false positives.
2. Apply a gaussian blur on the image to remove noise and small variations in the image.
3. Convert the image from BGR to HSV. HSV is more useful in this case as it separates the hue from the brightness of colours, making it more reliable under different lighting conditions.
4. Using cv2.inRange(), a binary mask is applied to the image, where the white parts of the image represent the areas that are within the tested thresholds for the green and red obstacles

5. Run cv2.SimpleBlobDetecctor() on the binary masks. It rejects blobs that are smaller than 650 pixels to remove any noise
For each colour detect_blobs() will only return the largest blob that is detected.

## Servos (Camera Swivel, Steering) - MG90

To calibrate the servos, we tested with different values from 500 to 2500 microseconds (µs) to find the centre, maximum and minimum.

Servo | Centre Max, Min (in degrees)
Camera | 1475 87
Steering | 1425 42

## I/O Interface (Button, LEDs)

In total, we have a button to start and stop the programme and three LEDS (red, yellow, green) to signal different messages for different challenges: open (red -- stationary, green -- running), obstacle (yellow -- stationary, green -- sees green obstacle, red -- sees red obstacle).

# Odometry

We use the wheel rotation and gyro to estimate the robot's pose (position and heading) while it is running.
- steer_in_dir(): steering (proportional control)
- augment_path(), augment_paths(): Steering back to line
| ○ Find path vector = (x2-x1) / (y2-y1)
| ○ Find distance of path
| ○ Find path vector in units
| ○ Find perpendicular path vector
| ○ Find path direction
- dot(): dot product
| ○ how far robot is off the path – drive_path()
| ○ how far robot has traveled along the path
- drive_path(), drive_paths():
- estimate_pose():
| ○ First version: looked at the heading and assumed a straight path based on the
| heading
| ○ Second version: treat the movement as an arc of a circle

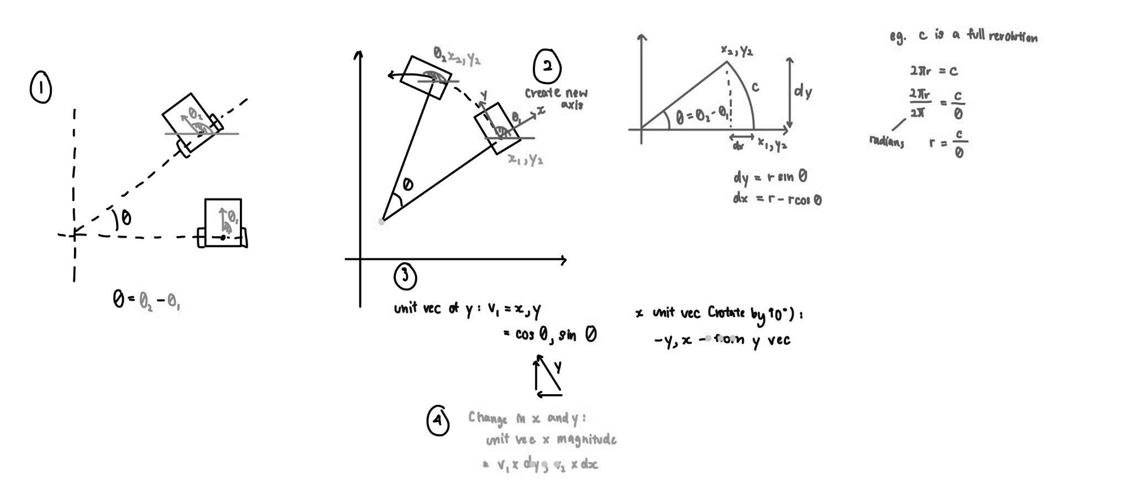
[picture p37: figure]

First, we take the centre of rotation as the origin, which means

θ = θ

2 − θ
1

d

y = rsinθ, d

x = rcosθ

r =

c
θ
in which c is the distance travelled

d

y =

c
θ

sinθ, d

x =

c
θ

cosθ

To apply this back to the original axis, we take the x, y vectors of the "morphed" graph, (rotate y

vector by 90 ), before we multiply the unit vectors with the local dx, dy to find the global dx, dy

o

y′ = (cosθ, sinθ)

x

′ = (− sinθ, cosθ)

d

X = x′ × d
x

, d

Y = y′ × d
y

Afterwards, we integrate other localisation methods on top of using odometry, by using a complementary filter.

# Localisation

## Spike Landmark (Old)

Initially, we used the spike landmark method during the 2025 season of WRO, but we wanted to improve our localisation method so we have since shifted to the Iterative Closest Point method.
Essentially, the method identifies which lidar readings are spikes or points of interest, in our case corners which are noticeably further away than the adjacent readings. Afterwards, we calculate if there is any difference between the supposed and actual cartesian coordinate of the landmark to find the error.
- Defined 8 landmarks: 4 inner corners, 4 outer corners, marked as green circles

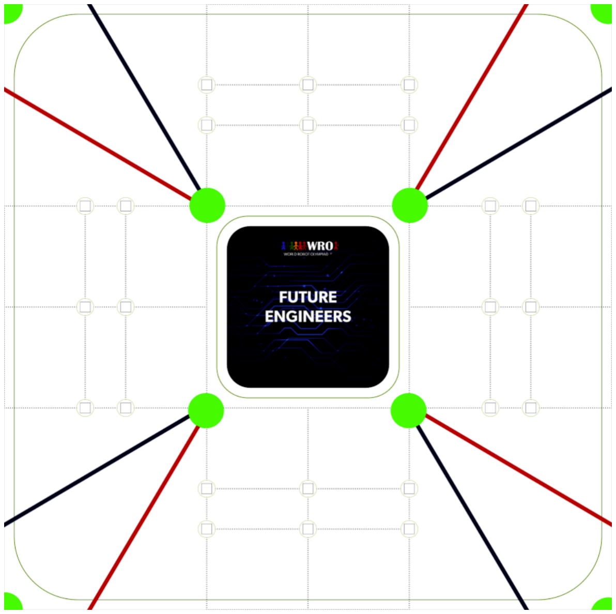
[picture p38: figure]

- add_cartesian(): convert lidar readings into cartesian coordinates
- identify_spikes()
- the different between two lidar measurements adjacent to the centre measurement have to show a significant difference
- filter out spikes within 250mm

- match_landmarks(): within 120mm, which we tested as the most optimal threshold
- calc_position_error(), calc_angle_error(): according to the spikes matched, we calculate the total error accumulated for x, y and heading (angle of the spike from the robot) separately before finding the average for each value and adding it to the odometry_pose
However, this method only uses a few points out of the approximate 400 we get from the lidar in comparison to the Iterative Closest Point method that makes full use of all the lidar readings.

## Iterative Closest Point (current)

- augment_walls(): Define the 8 walls on the playfield, getting their path vector, path direction, unit path vector and perpendicular path vector which are values needed
- add_cartesians(): same as the one used in the Spike Landmark
localise(): Let's start by transforming 1 point on a cartesian plane.
To handle the rotation, we can
Substitute | ,

Since the change in x, y and heading is going to be small as the frequency of the Coin-D4 is 10 Hertz, we can linearize the functions, by taking their gradients near 0.

Afterwards, we add translation as Tx, Ty

When we put it in a matrix form,

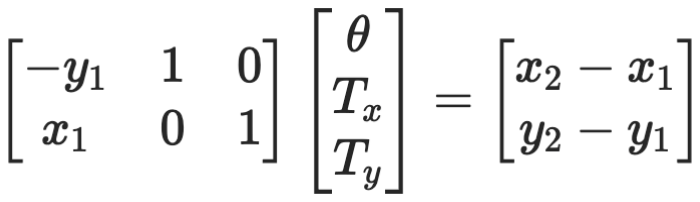
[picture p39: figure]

And we can add as many points as we want to the equation

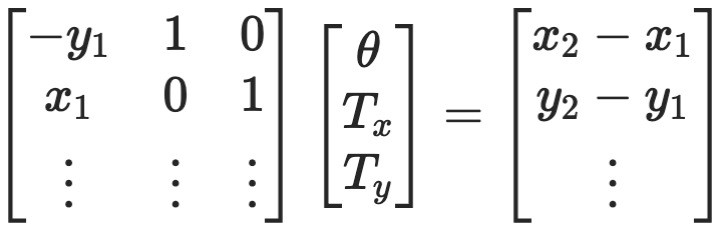
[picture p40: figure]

To solve this Ax = B, we take the pseudoinverse of A multiplied by B, which we calculate using the numpy library.
Now that we have the transformation matrix, we need to identify which point on the wall does the lidar reading correspond to, in our case we find the shortest perpendicular distance between each wall and the reading.

l is the vector of the lidar reading from the start of the wall: if it is a vertical wall, we only solve for the x-value and vice versa for a horizontal wall.
localise_iter(): Since we are dealing with an overdetermined system, there is no exact solution, but only a rough estimate. Running it with more iterations will help minimise the errors.

We tested it with a set of fake data which started with the mini-sets that have far fewer readings, before moving on to set 1 which has 360 points, closer to what we will expect in the actual run. After debugging, we realised that it was able to get close to the actual pose with only one iteration. Additionally, we timed it and it took roughly 1/50th of a second, meaning it is able to keep up with the lidar which takes 10 readings every 1 second.

# Complementary Filter

We set very small percentages for the localisation pose because we found that the odometry pose was already quite accurate.
POSITION_FILTER_RATIO = 0.1
HEADING_FILTER_RATIO = 0.01

# Camera Tracking

- Plotted points along the playfield, in between every pair of squares, where the obstacle could be placed
- Camera will track two points ahead of its current position
- Reused an existing function (dir_to_point) to calculate the angle the servo needs to turn to the obstacle, but adjusting the range to -180 to 180, as the function is used for cases where the range is 0 to 360

# Path following

- drive_path(), drive_paths():
- Find the error by taking the dot product of the unit vector perpendicular to the path and the vector from the start of the path to the robot (robot_vector):

perpendicular displacement = u

^
- r

→

- Get the correction / perpendicular distance of the robot from the path by multiplying the error by a gain
- Add the target_dir of the path with the correction which is what the robot will steer towards
- Keep checking the dist_travelled_along_path if it reaches the end by taking the dot product of the unit_path_vector and the robot vector: displacement along

path = p

^
- r

→

# Open Strategy

During the initialisation, the robot will assume it is moving clockwise and travel the first path until it reaches the corner: this is where the robot will read the distances from the lidar sensor for the points (0mm, 2700mm) and (1000mm, 2700mm). If the distance for the left point is greater than the right point, it will deduce that it is moving counterclockwise and update its pose accordingly. The reason why we chose these points instead of measuring the left and right distances is because we encountered some issues with determining the sides at certain start positions.

In the rest of the run, the robot will follow a preplanned clockwise and counterclockwise path, which is as close to the centre of the lanes as possible. By default, it would take the outermost path, 50 cm away from the outer wall. However, if the lidar detects that the first section of the inner wall is extended, the lane will shift closer to the wall such that it is 30 cm away from the outer wall.

We plan on improving our strategy by adjusting the paths to the inner paths where possible.

Pseudocode:

find initial position
first path run to confirm pose
main run:
(process described in general approach) if at ending position:
stop

# Obstacle Strategy

The robot will determine its direction (clockwise or counterclockwise) by getting the front, rear and side distances because the initial position is generally fixed. It will check if an obstacle is in front of it before moving back.

In the main run, the robot will switch between two fixed sets of paths, an outer and inner lane. Depending on the colour of the blocks in front, it will switch between the two paths to follow.

For example, if the robot is moving clockwise, detecting a red block will cause it to follow the inner paths, and vice versa for the green blocks. This will switch if the robot is moving counterclockwise. An improvement we made since 2025 is that we implemented camera tracking such that the camera follows the colour of the obstacle two sections ahead which ensures that the robot never misses the obstacle. In 2025, a major issue we had is that because our robot was larger and the field of vision of the robot was wider, we had to keep readjusting our paths so that the robot would not miss the obstacles, especially at the corners.

As of 25th August, the parking programme is still unfinished, but our strategy is to get into the exact position at the start of parking by moving the robot back and forth. As for the parallel parking procedure, it involves

(Scenario in which the parking area is on the right)

- Turn right to 45, move back till vehicle is facing 45
- Turn left to 0, move back till vehicle is behind the barrier
- Turn left to 45, move back tile vehicle is facing 0

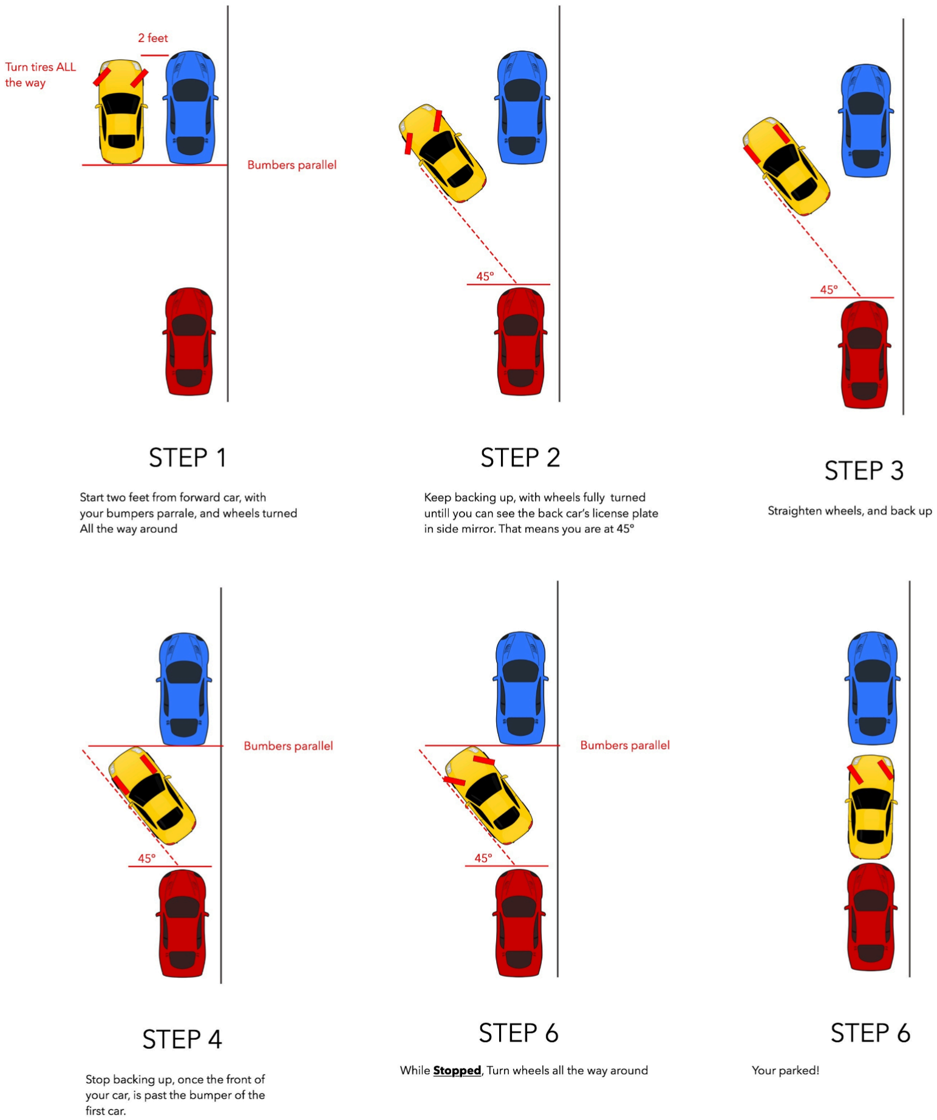
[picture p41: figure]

Pseudocode

find initial position
if obstacle in front: move back
main run:
(process described in general approach) if at ending position:
Parking

# Debugging / Telemetry tools

To make it easier to visualise the different variables — robot pose, lidar readings, matched spikes, colour of block detected - we created a telemetry software, using sockets to transfer data from the raspberrypi (client) to a computer (server) with our own protocol. We also keep the messages short so that it all fits in one packet and is not sent too frequently. Afterwards, we used tkinter to draw out the points on the playfield with the exact values written out at the left side of the interface.

Additionally, we changed our intialiser.sh file for easier debugging. Now, every time we run, the programme will log the standard output and error messages to a file with the date and time. To change the mode of the robot (sleep, open, obstacle), we will create a softlink between main_obstacle/open/sleep.py to main.py.

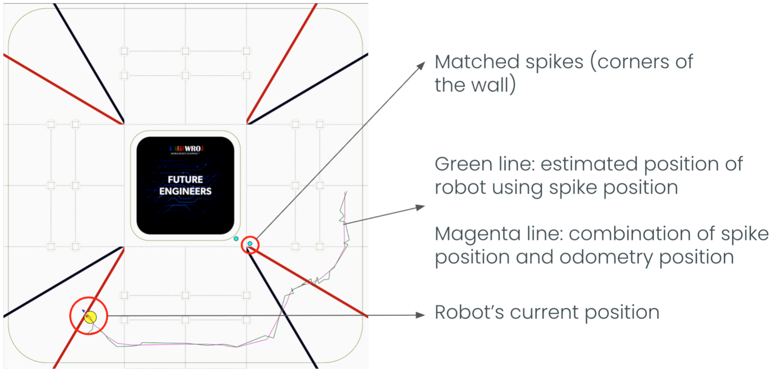
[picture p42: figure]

# Hardware Documentation

After a long break from WRO Internationals 2025, we decided to come back to the studio and start work on our next robot for Future Engineers 2026. While our 2025 FE robot was commendable, it had multiple flaws that needed fixing. Upon starting our preparation, we always fix the mechanical issues first, before moving on to improving our code for the robot itself. As such, we came together and formed a list of flaws that our previous robot had.
- Large robot base - in turn causing a wide turning radius
- Led to many near-miss instances of the robot and the obstacles during our obstacle challenge runs in the competition
- Servo motor for our steering mechanism was not centred
- To adapt to this issue, we initially cut a slot in our steering component for the parts to have more slack when turning, making it smoother
- However, this slack in the parts also caused the steering mechanism itself to be quite unsturdy and loose, which could sometimes lead to inaccurate turns in our robot runs
- Steering wheel components were loose - attached only by the pivot point, and nowhere else
- Because of the singular mounting point, the steering wheel segments often started to bend outwards, due to the force being applied downwards on the base because of our electronic components on the top plate of the robot
- As the steering wheels bend outwards, steering starts to become less smooth, and turning radius is also slightly affected
- Even worse, our steering wheels would sometimes come out due to this looseness issue
- However, this looseness did provide a small amount of suspension for our robot, which allowed it to have more grip on uneven surfaces (at times when the field can get slightly offset)
- Camera was fixed in one direction - entire robot had to turn to allow the camera to see obstacles on the far end of its POV
- Despite using a wide angle lens for our camera last year, it was often not wide enough to detect obstacles at the far end, which may sometimes not appear in the camera’s POV
- Results in making incorrect movements to avoid the obstacles, losing points for our competition runs

After forming this list of main issues, we decided to tackle these issues one by one, throughout a few studio sessions.

# Reducing robot base size

The first issue we fixed was the large robot base. This problem arguably had the most significant impact on our performance, as it was the lead contributor to our failed runs last year. Because of this significance, this issue also came with major changes that had to be done to our robot. This is because simply shrinking our robot frame was not as easy as it seemed; we would need to make our drive base + our Ackermann Steering segment significantly more compact, as well as shrink the layout of our electronic components on the top plate. This process would last a few sessions, but we mainly focused on shrinking the drive base this session.

Initially, our drive base motor, driving the entire RWD module, was mounted perpendicular to the RWD module itself.

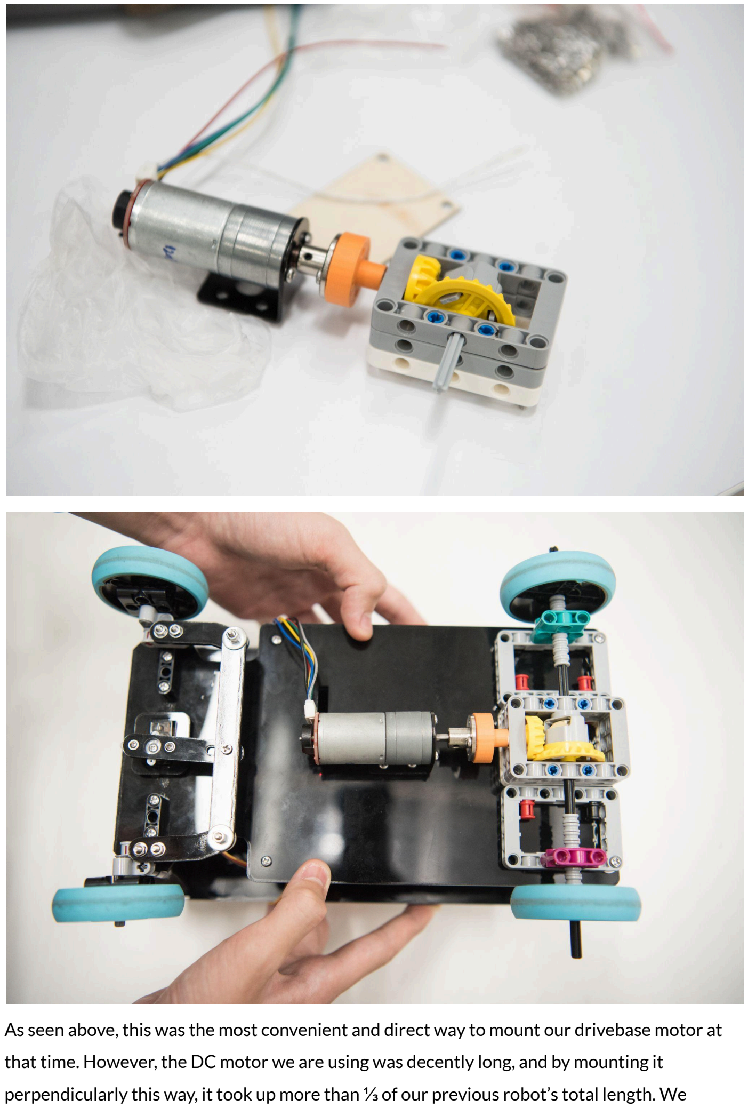
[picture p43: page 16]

As seen above, this was the most convenient and direct way to mount our drivebase motor at that time. However, the DC motor we are using was decently long, and by mounting it perpendicularly this way, it took up more than ⅓ of our previous robot’s total length. We realised that if we wanted to make our robot smaller and more compact, we would need to mount this DC motor in another way.

As such, we started to take apart our previous RWD module, and start from scratch again.

After significantly reducing the size of the RWD module, we still had to similarly reduce the size of our Ackermann Steering module in the front of the base plate, so that we could then reduce the size of the entire base plate. Initially, our steering module was not designed to be compact, as it was our first ever iteration. However, in last year’s competition, because of how wide our turning radius was, the robot often struggled to avoid the obstacles during its runs. The solution to this came in two parts; one was to shorten the length of our robot, reducing the distance between our front and back wheels; and the other was to reduce the distance between our steering wheels, to make our steering angle sharper.

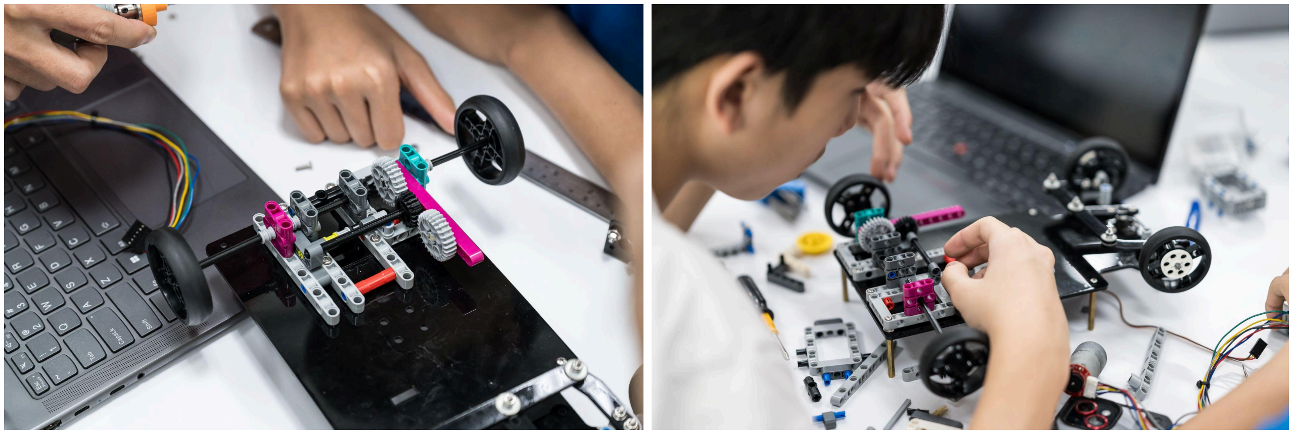
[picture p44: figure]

Over multiple prototypes and a tedious process of trial and error, we eventually built a suitable RWD module that was much more compact than the previous iteration. This was mainly achieved by mounting our DC motor parallel to the RWD module, instead of perpendicular. This cut approximately 8-9cm from the total length of our robot base, a significant cut from our previous robot.

However, mounting the DC motor in a parallel orientation came with a few issues, mainly because the motor would either be too close or too far to the rotating differential gear and shaft. The solution that we eventually found was to gear the DC motor shaft to our main RWD module shaft. This ensured our motor was mounted in an optimal position, while also slightly increasing the speed of our drive base due to the gear ratio of the shafts.

In addition, there was a lot of useless space taken up by our wheel shafts that could be cut from both sides to reduce the width of our robot. After all these changes, our new RWD module looked like this:

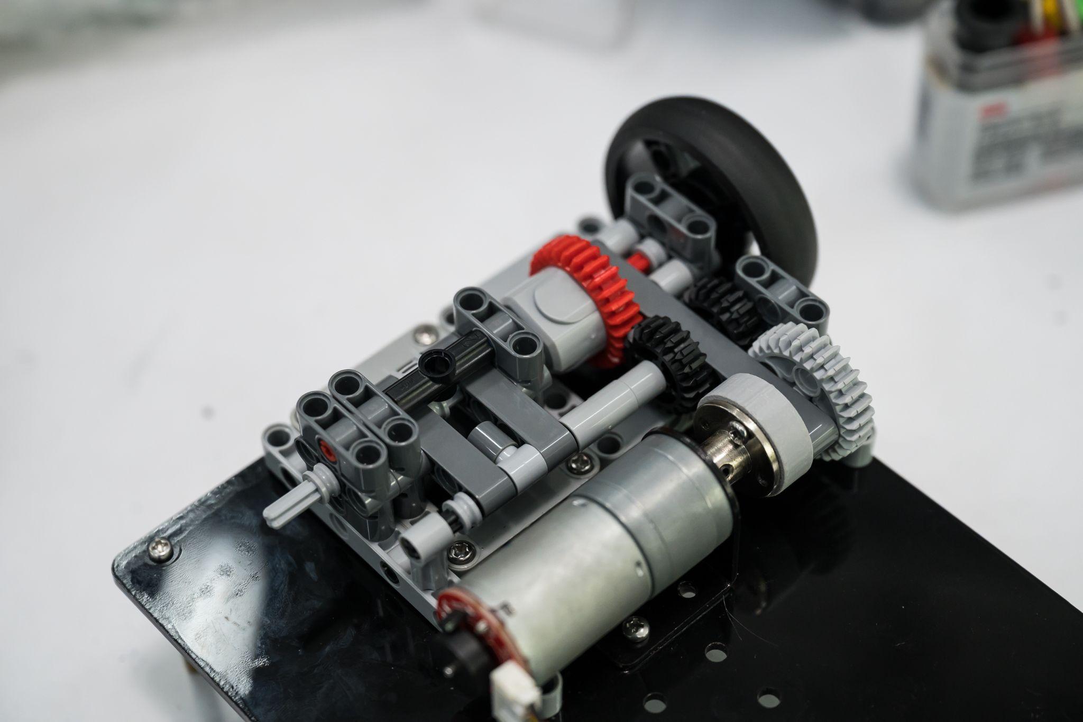
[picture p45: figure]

Ultimately, we not only cut 8cm in length, but also 4-5cm in width.

After significantly reducing the size of the RWD module, we still had to similarly reduce the size of our Ackermann Steering module in the front of the base plate, so that we could then reduce the size of the entire base plate. Initially, our steering module was not designed to be compact, as it was our first ever iteration.

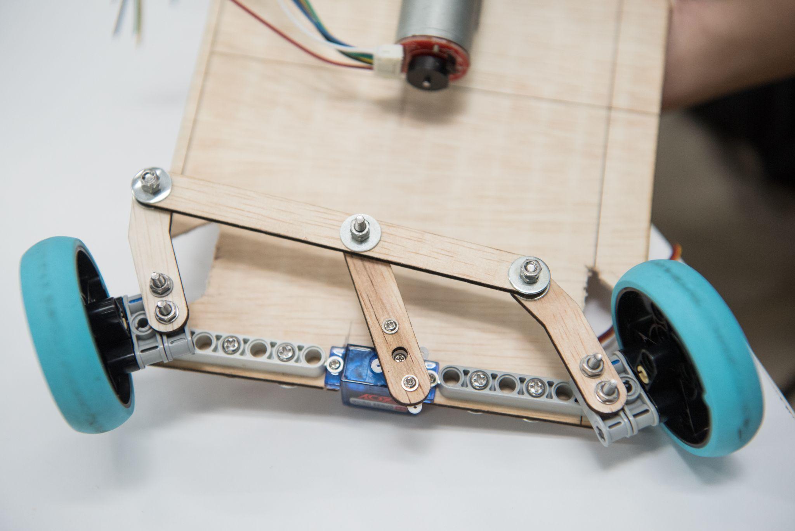
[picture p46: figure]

(^^ first steering mech iteration)

However, in last year’s competition, because of how wide our turning radius was, the robot often struggled to avoid the obstacles during its runs. The solution to this came in two parts; one was to shorten the length of our robot, reducing the distance between our front and back wheels; and the other was to reduce the distance between our steering wheels, to make our steering angle sharper. As seen in the image above, the distance between both our steering wheels could be reduced by quite a substantial amount, allowing our robot’s width to be reduced as a whole. This fix was pretty straightforward and simple, and after a short period of time, we were able to reduce the size of the steering module.

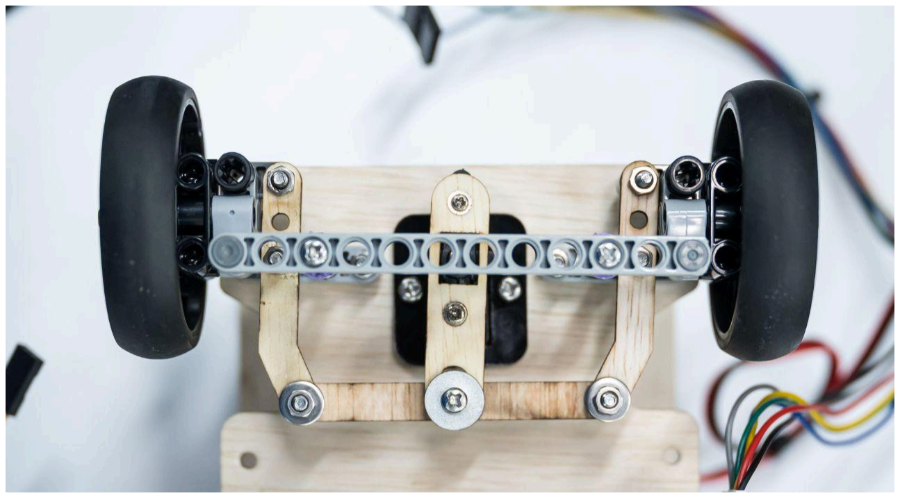
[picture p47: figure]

Comparing both iterations of our Ackermann Steering mechanism, we can see that the distance between both wheels has been shortened from ~18 Lego Technic holes to ~13 Lego Technic holes, which is equivalent to ~40mm, or 4cm. Because of this change in width, the length of our Ackermann steering liftarms also had to be edited accordingly to account for this difference. By designing the liftarms online, this process was very fast and we managed to cut out the new liftarms with plywood and connect them quickly.

In our previous robot, the shaft connecting our wheel components to our main robot base plate was short, and only supported by a height of two lego beams. This meant that the shaft still had leeway to bend slightly.

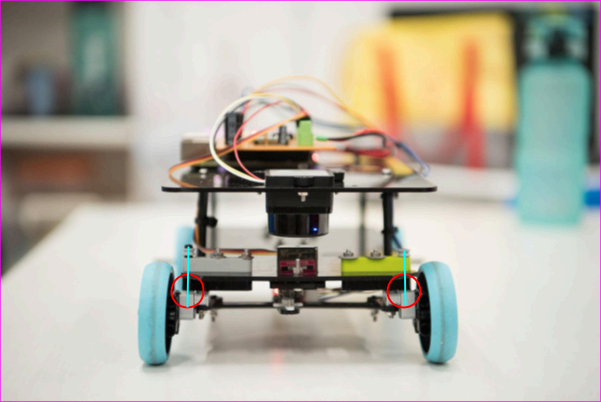
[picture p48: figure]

As seen above, our previous robot is in a stationary state, and the wheels are already bending outwards slightly. The connection point, indicated by the red circle, is the only connection point for each wheel.
Fix #1: We redesigned the component linking the shaft, Ackermann liftarm and rotating wheel together, so that the shaft would be supported by 5 Lego beams compared to 2.

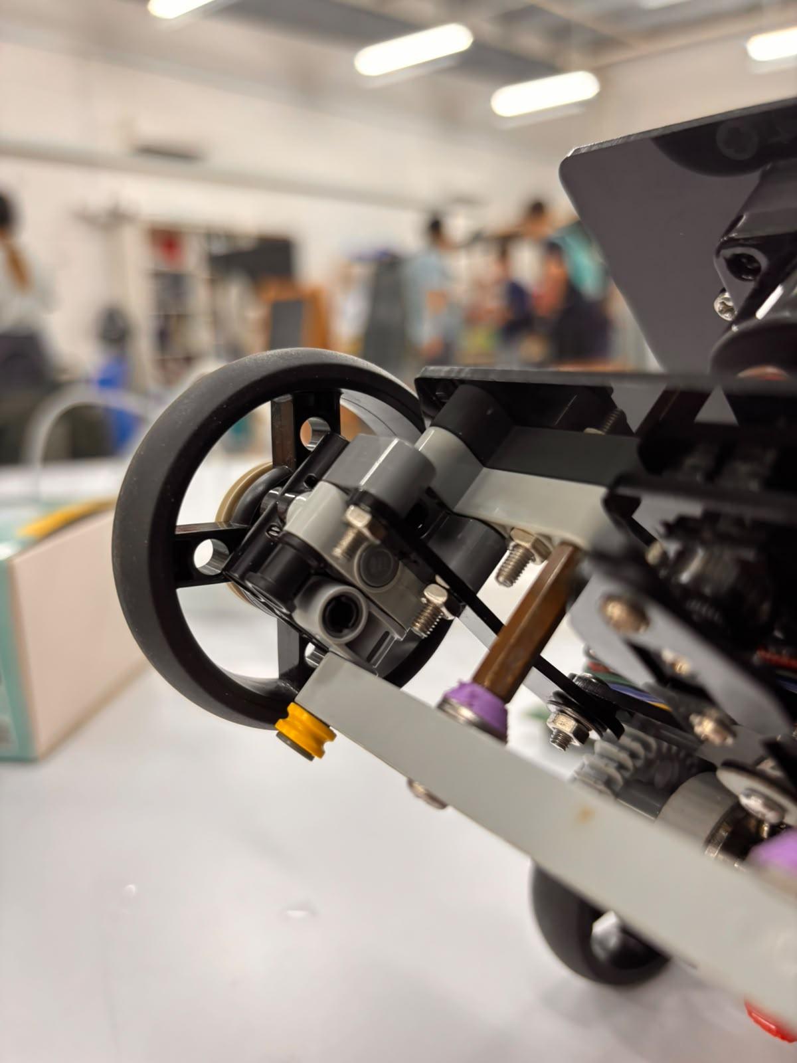
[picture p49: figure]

Fix #2: Instead of the wheel components having only one connection point on the top, we added a liftarm below the wheel components, linking both wheels together. This beam pulls both wheel shafts together, ensuring both beams remain parallel to each other, and remain perpendicular to the ground.

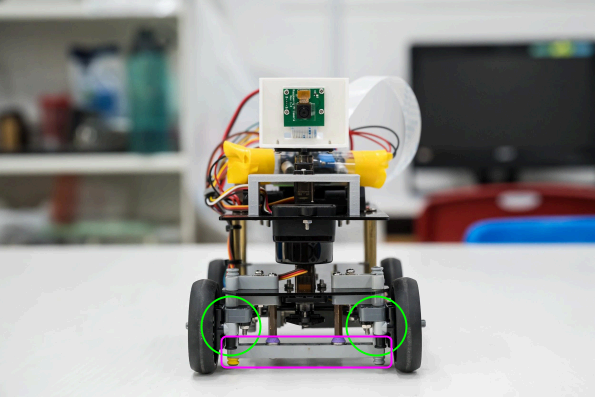
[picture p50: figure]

As indicated by the green circles, it shows fix #1, our new and improved wheel module, and the pink rectangle indicates fix #2, the beam that braces both wheels together. In addition, we braced the beam to the main robot baseplate using two short standoffs, which doubled up as a limiter for our Ackermann Steering linkage mechanism, preventing this mechanism from “overlocking”. Overlocking occurs when both Ackermann liftarms form a straight line with the pivot point, and when the servo motor tries to turn back, the force is exerted straight through the joints instead of turning them, since there is zero leverage to start the rotation. By using these standoffs, it prevents the liftarms from aligning to a straight line, and maintains leverage for continuous rotation and steering.

# Centering Steering Servo

Another issue with our previous robot was the slight inaccuracy in design in our first iteration of our Ackermann Steering module. In our previous robot, we mounted the steering servo motor, by centering the rectangular shape of the servo on the robot base plate. However, this was an issue, as the actual point of rotation is slightly offset from the centre of the rectangular servo motor. As a result, we had to cut a long slot on our Ackermann liftarm to account for this slight inaccuracy, in turn making our steering looser than usual.

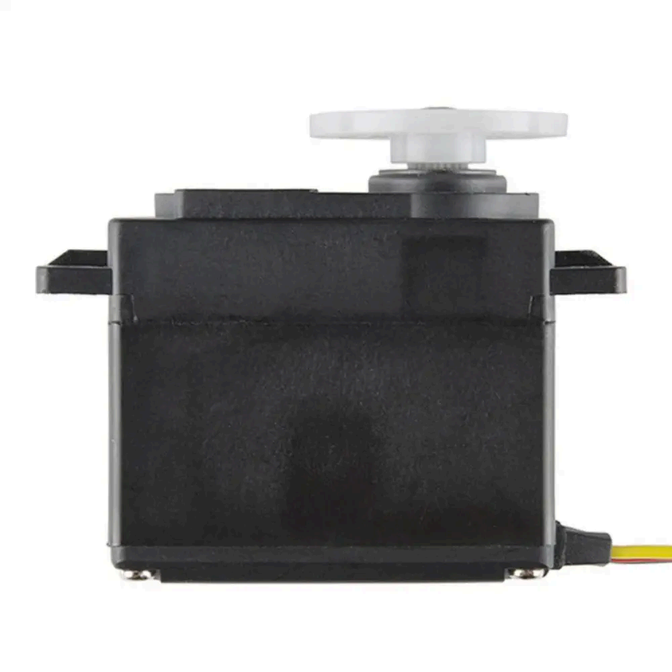
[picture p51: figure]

To fix this issue, we had two options. The first option was to mount this servo motor in the same orientation, but offset it slightly to the left to account for the offset of the centre of rotation. The second option was to rotate this servo motor 90 degrees, so the short side of the motor faces the front of the robot. In this way, the centre of rotation does remain centred, while the entire servo motor is also centred to the robot. The former option, however, did not work after testing, as the servo motor would hit the Ackermann Steering bracing on either side of the robot, and thus would not fit if the orientation was kept the same. As such, we decided to go with the latter option. This fix was simple enough, as we just needed to rotate the rectangular slot for the servo motor on our robot base plate CAD file. Soon after, we adjusted our Ackermann steering liftarms accordingly, and our Ackermann Steering module was complete.

# Adding Camera Servo

The last main hardware issue we found in our previous robot was the intermittent blindspots of our camera. Despite using a wide-angle lens for our camera, our robot always tends to miss obstacles at the very edge of the Camera’s POV, especially at junctions requiring sharp turns. As such, we decided to make a significant mechanical change to how our camera was mounted. Instead of just a fixed and stationery mount, we decided to attach our camera to a servo motor, with a functionality similar to that of a Camera Gimbal module. To achieve this functionality, we first had to find a way to mount the servo motor on the top plate of our robot, while not interfering with the other electronic components.

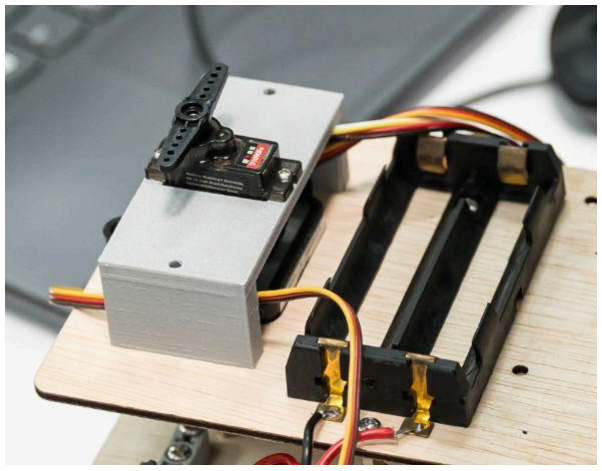
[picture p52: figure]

As seen above, the most convenient location we found for our servo motor was to mount it on top of our lidar sensor. This was achieved by designing a custom 3D printed elevated bracket, fastened to the top plate, that allows our servo motor to fit perfectly on top. Thereafter, we quickly attached the camera bracket together with the camera itself, and the rotating camera module was complete.

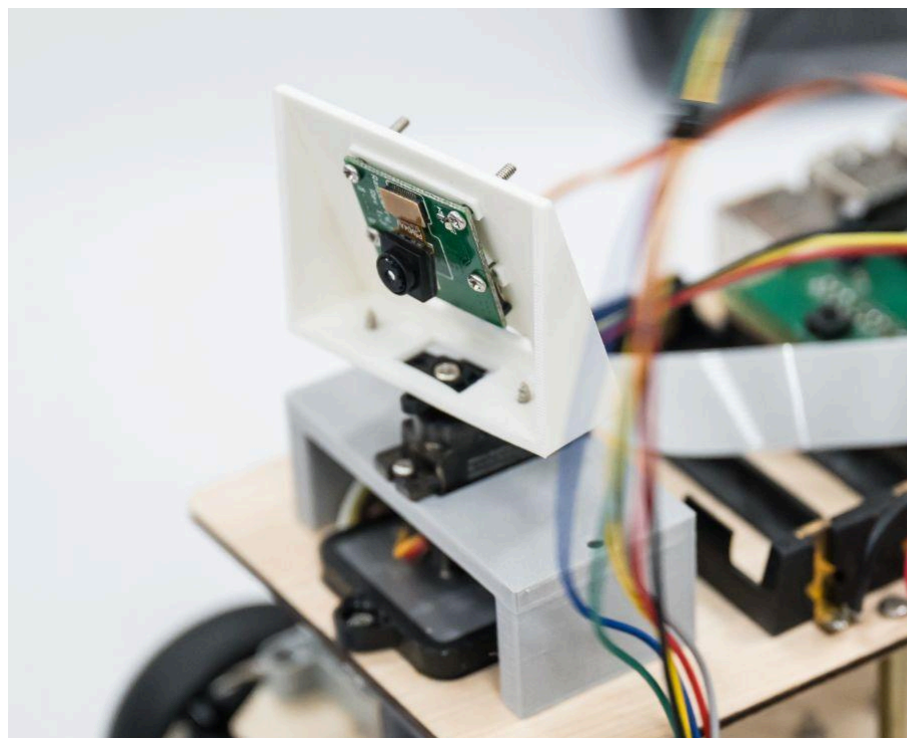
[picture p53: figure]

# PCB

We also redesigned the PCB such that it fits on the smaller top plate without interfering with the battery holder before sending it out for printing through JLCPCB

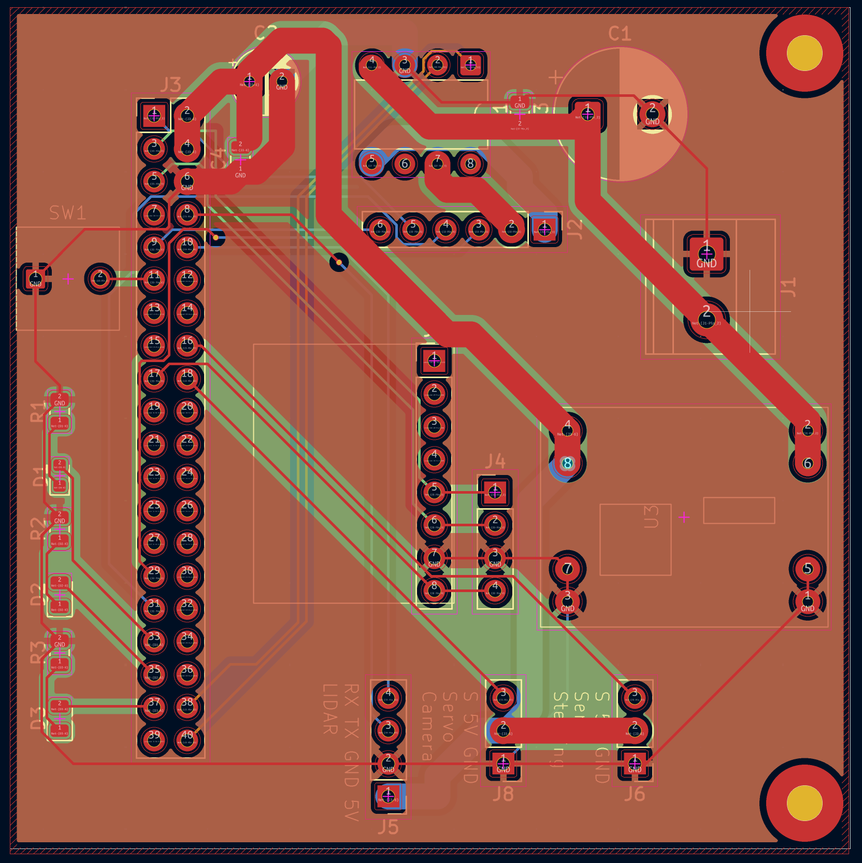
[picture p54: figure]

We only realised after inserting the PCB onto the raspberrypi that the 2x20 connectors were in the wrong orientation, which almost short circuited the raspberrypi, so we had to redesign the PCB board.

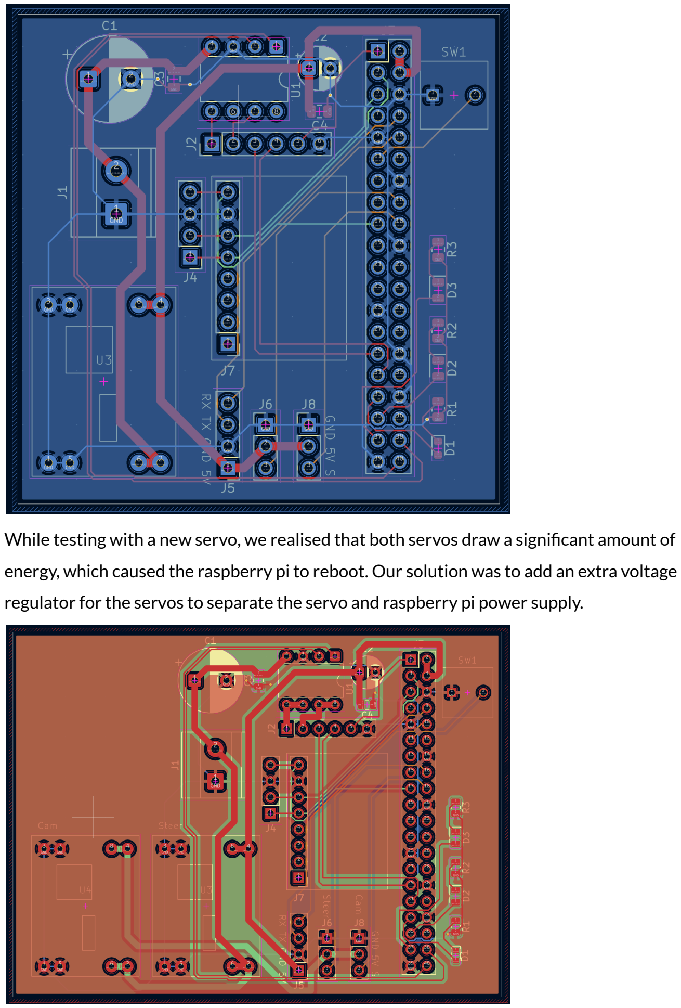
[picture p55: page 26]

While testing with a new servo, we realised that both servos draw a significant amount of energy, which caused the raspberry pi to reboot. Our solution was to add an extra voltage regulator for the servos to separate the servo and raspberry pi power supply.

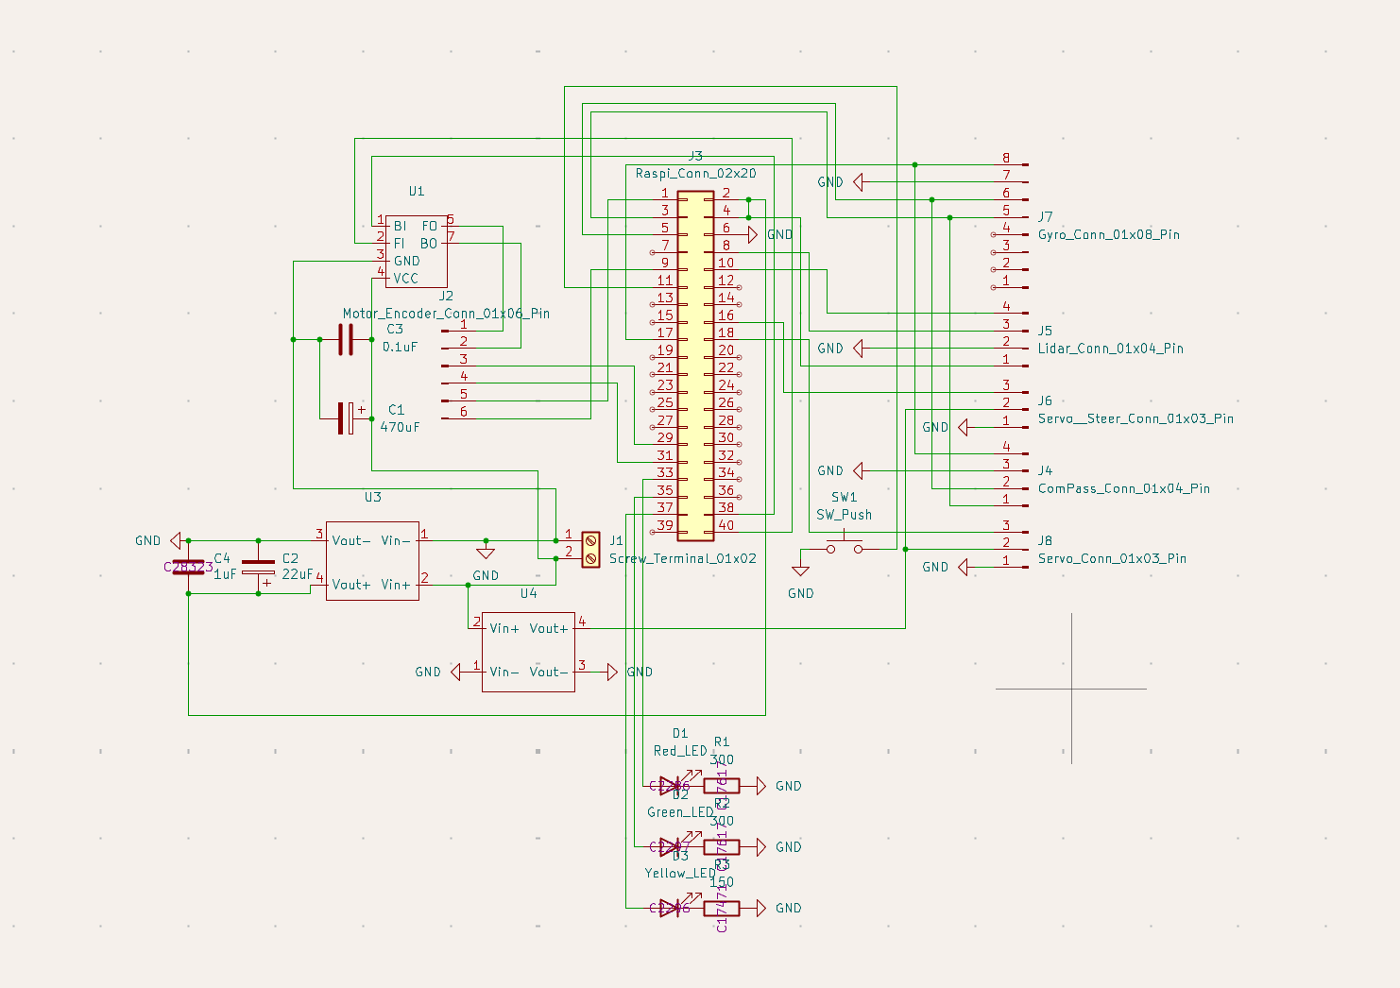
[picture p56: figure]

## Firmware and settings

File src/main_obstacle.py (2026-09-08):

import time

import drive
import initialise_hardware as initialise_hardware
import initialise_pose as initialise_pose
import telemetry_client as telemetry_client
import sensors as sensors
import odometry as odometry
import point_cloud_localisation as localisation
import complementary_filter as complementary_filter
import navigation as navigation
import rpicam as rpicam
import led as led
from utilities import * 
from paths import cw_obstacle_inner_paths, cw_obstacle_outer_paths, ccw_obstacle_inner_paths, ccw_obstacle_outer_paths, cw_parking_path, ccw_parking_path, cw_obstacle_first_inner_paths, cw_obstacle_first_outer_paths, ccw_obstacle_first_inner_paths, ccw_obstacle_first_outer_paths
from obstacles import cw_obstacle_positions, ccw_obstacle_positions

USE_TELEMETRY = False
SPEED = 250 
PATHS_LIMIT = 48  # full run is 48, 16 per round
MODE = "obstacle"

def sleep_with_update(dur, debug=False):
    global pose

    end_time = time.time() + dur
    loc = 0
    while time.time() < end_time:
        sensor_readings = sensors.read(devices)
        localised_pose = localisation.localise(pose, sensor_readings, MODE)
        if localised_pose: 
            # print(sensor_readings['lidar'])
            loc += 1
            pose = localised_pose
            if debug:
                print('sleep', localised_pose)

    if debug:
        print(pose, loc)

def parking_cw():
    global pose

    print("starting parking procedure", pose)

    fwd_stop_y = parking_path[1][1]
    rear_stop_y = 1080
    x_min = parking_path[0][0] - 15
    x_max = parking_path[0][0] + 15
    y_min = 1410 - 5
    y_max = 1410 + 5

    prev_time = time.time()
    parking_start_pos_reached = False

    while True:

        # Move Forward
        while pose[1] < fwd_stop_y: 
            sensor_readings = sensors.read(devices)
            odometry_pose = odometry.estimate_pose(pose, sensor_readings)
            localised_pose = localisation.localise(odometry_pose, sensor_readings, MODE)
            if localised_pose: 
                pose = complementary_filter.merge(odometry_pose, localised_pose)
                print("localised pose: ", odometry_pose, localised_pose, pose)
            else:
                pose = odometry_pose
            nav.drive_path(parking_path, pose, 175)
            if (time.time() - prev_time) > 0.5:
                print(pose)
                prev_time = time.time()
            if ((x_min < pose[0] < x_max) and (y_min < pose[1] < y_max) and (87 < (pose[2] % 360) < 93)):
                parking_start_pos_reached = True
                break

        if parking_start_pos_reached:
            devices["drive"].drive(0)
            devices["drive"].steering(0)
            print("parking starting pos pt 1 reached", pose)
            break    

        # Move backward
        while pose[1] > rear_stop_y: 
            sensor_readings = sensors.read(devices)
            odometry_pose = odometry.estimate_pose(pose, sensor_readings)
            localised_pose = localisation.localise(odometry_pose, sensor_readings, MODE)
            if localised_pose: 
                pose = complementary_filter.merge(odometry_pose, localised_pose)
                print("localised pose: ", odometry_pose, localised_pose, pose)
            else:
                pose = odometry_pose

            nav.drive_path_back(parking_path, pose, 200)
            if (time.time() - prev_time) > 0.5:
                print(pose)
                prev_time = time.time()
            if ((x_min < pose[0] < x_max) and (y_min < pose[1] < y_max) and (87 < (pose[2] % 360) < 93)):
                parking_start_pos_reached = True
                break

    nav.stop()

    # Parking 
    devices["drive"].steering(-45)
    devices["drive"].drive(-150)

    move_back_1_stop_y = 1290
    while pose[1] > move_back_1_stop_y: 
        sensor_readings = sensors.read(devices)
        odometry_pose = odometry.estimate_pose(pose, sensor_readings)
        localised_pose = localisation.localise(odometry_pose, sensor_readings, MODE)
        if localised_pose: 
            pose = complementary_filter.merge(odometry_pose, localised_pose)
            print("localised pose: ", odometry_pose, localised_pose, pose)
        else:
            pose = odometry_pose

    devices["drive"].drive(0)
    print('end pose1: ', pose) 

    sleep_with_update(0.3)
    devices["drive"].steering(0)
    sleep_with_update(0.3)

    devices["drive"].drive(-150)

    move_back_1_stop_y = 1230
    while pose[1] > move_back_1_stop_y: 
        sensor_readings = sensors.read(devices)
        odometry_pose = odometry.estimate_pose(pose, sensor_readings)
        localised_pose = localisation.localise(odometry_pose, sensor_readings, MODE)
        if localised_pose: 
            pose = complementary_filter.merge(odometry_pose, localised_pose)
            print("localised pose: ", odometry_pose, localised_pose, pose)
        else:
            pose = odometry_pose


    print('end pose3: ', pose) 
    devices["drive"].drive(0)

    sleep_with_update(0.3)
    devices["drive"].steering(45)
    sleep_with_update(0.3)

    devices["drive"].drive(-100)

    move_back_2_stop_y = 1160
    while pose[1] > move_back_2_stop_y: 
        sensor_readings = sensors.read(devices)
        odometry_pose = odometry.estimate_pose(pose, sensor_readings)
        localised_pose = localisation.localise(odometry_pose, sensor_readings, MODE)
        if localised_pose: 
            pose = complementary_filter.merge(odometry_pose, localised_pose)
        else:
            pose = odometry_pose

    print('end pose4: ', pose) 
    devices["drive"].drive(0)
    # devices["drive"].steering(45)
    sleep_with_update(0.3)

    forward_stop_y = 1200
    while pose[1] < forward_stop_y:
        sensor_readings = sensors.read(devices)
        odometry_pose = odometry.estimate_pose(pose, sensor_readings)
        localised_pose = localisation.localise(odometry_pose, sensor_readings, MODE)
        if localised_pose: 
            pose = complementary_filter.merge(odometry_pose, localised_pose)
            print("localised pose: ", odometry_pose, localised_pose, pose)
        else:
            pose = odometry_pose
        devices["drive"].steer_p(90, pose[2], 75, gain=4)

    devices["drive"].drive(0)
    sleep_with_update(0.3)
    print('end pose end of stage 2: ', pose) 

    # Stage 3
    while pose[0] > 120:
        # Back 1
        devices["drive"].steering(-45)
        sleep_with_update(0.1)
        devices["drive"].drive(-75)

        move_back_2_stop_y = 1180
        while pose[1] > move_back_2_stop_y: 
            sensor_readings = sensors.read(devices)
            odometry_pose = odometry.estimate_pose(pose, sensor_readings)
            localised_pose = localisation.localise(odometry_pose, sensor_readings, MODE)
            if localised_pose: 
                pose = complementary_filter.merge(odometry_pose, localised_pose)
            else:
                pose = odometry_pose

        devices["drive"].drive(0)
        sleep_with_update(0.3)
        print("end pose stage 2-1: ", pose)

        devices["drive"].steering(45)
        sleep_with_update(0.3)
        devices["drive"].drive(-75)

        move_back_2_stop_y = 1130
        while pose[1] > move_back_2_stop_y: 
            sensor_readings = sensors.read(devices)
            odometry_pose = odometry.estimate_pose(pose, sensor_readings)
            localised_pose = localisation.localise(odometry_pose, sensor_readings, MODE)
            if localised_pose: 
                pose = complementary_filter.merge(odometry_pose, localised_pose)
            else:
                pose = odometry_pose

        devices["drive"].drive(0)
        sleep_with_update(0.3)

        nav.stop()
        sleep_with_update(0.3)
        print('end pose stage 2-2: ', pose) 

        # forward
        devices["drive"].steering(-45)
        sleep_with_update(0.3)
        devices["drive"].drive(75)

        forward_stop_y = 1150
        while pose[1] < forward_stop_y: 
            sensor_readings = sensors.read(devices)
            odometry_pose = odometry.estimate_pose(pose, sensor_readings)
            localised_pose = localisation.localise(odometry_pose, sensor_readings, MODE)
            if localised_pose: 
                pose = complementary_filter.merge(odometry_pose, localised_pose)
            else:
                pose = odometry_pose

        devices["drive"].drive(0)
        sleep_with_update(0.3)
        print("end pose stage 2-3: ", pose)

        forward_stop_y = 1205
        while pose[1] < forward_stop_y: 
            sensor_readings = sensors.read(devices)
            odometry_pose = odometry.estimate_pose(pose, sensor_readings)
            localised_pose = localisation.localise(odometry_pose, sensor_readings, MODE)
            if localised_pose: 
                pose = complementary_filter.merge(odometry_pose, localised_pose)
            else:
                pose = odometry_pose
            devices["drive"].steer_p(90, pose[2], 75, gain=4)

        devices["drive"].drive(0)
        sleep_with_update(0.3)

        print('end pose stage 2-4: ', pose) 

    print("end pose: ", pose)

def parking_ccw():
    global pose

    print("starting parking procedure", pose)

    fwd_stop_y = parking_path[1][1]
    rear_stop_y = 1800
    x_min = parking_path[0][0] - 15
    x_max = parking_path[0][0] + 15
    y_min = 2140 - 5
    y_max = 2140 + 5

    prev_time = time.time()
    parking_start_pos_reached = False

    # Parking stage 1
    while True:
        # Move Forward
        while pose[1] < fwd_stop_y: 
            sensor_readings = sensors.read(devices)
            odometry_pose = odometry.estimate_pose(pose, sensor_readings)
            localised_pose = localisation.localise(odometry_pose, sensor_readings, MODE)
            if localised_pose: 
                pose = complementary_filter.merge(odometry_pose, localised_pose)
                print("localised pose: ", odometry_pose, localised_pose, pose)
            else:
                pose = odometry_pose
            nav.drive_path(parking_path, pose, 175)
            if (time.time() - prev_time) > 0.5:
                # print(pose)
                prev_time = time.time()
            if ((x_min < pose[0] < x_max) and (y_min < pose[1] < y_max) and (87 < (pose[2] % 360) < 93)):
                parking_start_pos_reached = True
                break

        if parking_start_pos_reached:
            devices["drive"].drive(0)
            devices["drive"].steering(0)
            print("parking starting pos pt 1 reached", pose)
            break    

        # Move backward
        while pose[1] > rear_stop_y: 
            sensor_readings = sensors.read(devices)
            odometry_pose = odometry.estimate_pose(pose, sensor_readings)
            localised_pose = localisation.localise(odometry_pose, sensor_readings, MODE)
            if localised_pose: 
                pose = complementary_filter.merge(odometry_pose, localised_pose)
                print("localised pose: ", odometry_pose, localised_pose, pose)
            else:
                pose = odometry_pose

            nav.drive_path_back(parking_path, pose, 200)
            if (time.time() - prev_time) > 0.5:
                # print(pose)
                prev_time = time.time()
            if ((x_min < pose[0] < x_max) and (y_min < pose[1] < y_max) and (87 < (pose[2] % 360) < 93)):
                parking_start_pos_reached = True
                break

    nav.stop()

    # Parking stage 2

    # Back 1: 45 deg
    devices["drive"].steering(45)
    devices["drive"].drive(-150)

    move_back_1_stop_y = 2015 
    while pose[1] > move_back_1_stop_y: 
        sensor_readings = sensors.read(devices)
        odometry_pose = odometry.estimate_pose(pose, sensor_readings)
        localised_pose = localisation.localise(odometry_pose, sensor_readings, MODE)
        if localised_pose: 
            pose = complementary_filter.merge(odometry_pose, localised_pose)
            print("localised pose: ", odometry_pose, localised_pose, pose)
        else:
            pose = odometry_pose

    devices["drive"].drive(0)
    print('end pose1: ', pose) 

    # Back 2: 0 deg
    sleep_with_update(0.3)
    devices["drive"].steering(0)
    sleep_with_update(0.3)

    devices["drive"].drive(-150)

    move_back_1_stop_y = 1950 
    while pose[1] > move_back_1_stop_y: 
        sensor_readings = sensors.read(devices)
        odometry_pose = odometry.estimate_pose(pose, sensor_readings)
        localised_pose = localisation.localise(odometry_pose, sensor_readings, MODE)
        if localised_pose: 
            pose = complementary_filter.merge(odometry_pose, localised_pose)
            print("localised pose: ", odometry_pose, localised_pose, pose)
        else:
            pose = odometry_pose


    print('end pose3: ', pose) 
    devices["drive"].drive(0)

    # Back 3: -45 deg
    sleep_with_update(0.3)
    devices["drive"].steering(-45)
    sleep_with_update(0.3)

    devices["drive"].drive(-100)

    move_back_2_stop_y = 1880
    while pose[1] > move_back_2_stop_y: 
        sensor_readings = sensors.read(devices)
        odometry_pose = odometry.estimate_pose(pose, sensor_readings)
        localised_pose = localisation.localise(odometry_pose, sensor_readings, MODE)
        if localised_pose: 
            pose = complementary_filter.merge(odometry_pose, localised_pose)
        else:
            pose = odometry_pose

    print('end pose4: ', pose) 
    devices["drive"].drive(0)
    # devices["drive"].steering(45)
    sleep_with_update(0.3)

    # Forward: straigten to heading 90
    forward_stop_y = 1930
    while pose[1] < forward_stop_y:
        sensor_readings = sensors.read(devices)
        odometry_pose = odometry.estimate_pose(pose, sensor_readings)
        localised_pose = localisation.localise(odometry_pose, sensor_readings, MODE)
        if localised_pose: 
            pose = complementary_filter.merge(odometry_pose, localised_pose)
            print("localised pose: ", odometry_pose, localised_pose, pose)
        else:
            pose = odometry_pose
        devices["drive"].steer_p(90, pose[2], 75)

    devices["drive"].drive(0)
    sleep_with_update(0.3)
    print('end pose end of stage 2: ', pose) 

    # Stage 3
    while pose[0] < 2880:
        # Back 1
        devices["drive"].steering(45)
        sleep_with_update(0.1)
        devices["drive"].drive(-75)

        move_back_2_stop_y = 1910
        while pose[1] > move_back_2_stop_y: 
            sensor_readings = sensors.read(devices)
            odometry_pose = odometry.estimate_pose(pose, sensor_readings)
            localised_pose = localisation.localise(odometry_pose, sensor_readings, MODE)
            if localised_pose: 
                pose = complementary_filter.merge(odometry_pose, localised_pose)
            else:
                pose = odometry_pose

        devices["drive"].drive(0)
        sleep_with_update(0.3)
        print("end pose stage 2-1: ", pose)

        devices["drive"].steering(-45)
        sleep_with_update(0.3)
        devices["drive"].drive(-75)

        move_back_2_stop_y = 1860
        while pose[1] > move_back_2_stop_y: 
            sensor_readings = sensors.read(devices)
            odometry_pose = odometry.estimate_pose(pose, sensor_readings)
            localised_pose = localisation.localise(odometry_pose, sensor_readings, MODE)
            if localised_pose: 
                pose = complementary_filter.merge(odometry_pose, localised_pose)
            else:
                pose = odometry_pose

        devices["drive"].drive(0)
        sleep_with_update(0.3)

        sleep_with_update(0.3)
        print('end pose stage 2-2: ', pose) 

        # forward
        devices["drive"].steering(45)
        sleep_with_update(0.3)
        devices["drive"].drive(75)

        forward_stop_y = 1880
        while pose[1] < forward_stop_y: 
            sensor_readings = sensors.read(devices)
            odometry_pose = odometry.estimate_pose(pose, sensor_readings)
            localised_pose = localisation.localise(odometry_pose, sensor_readings, MODE)
            if localised_pose: 
                pose = complementary_filter.merge(odometry_pose, localised_pose)
            else:
                pose = odometry_pose

        devices["drive"].drive(0)
        sleep_with_update(0.3)
        print("end pose stage 2-3: ", pose)

        forward_stop_y = 1935
        while pose[1] < forward_stop_y: 
            sensor_readings = sensors.read(devices)
            odometry_pose = odometry.estimate_pose(pose, sensor_readings)
            localised_pose = localisation.localise(odometry_pose, sensor_readings, MODE)
            if localised_pose: 
                pose = complementary_filter.merge(odometry_pose, localised_pose)
            else:
                pose = odometry_pose
            devices["drive"].steer_p(90, pose[2], 75)

        devices["drive"].drive(0)
        sleep_with_update(0.3)

        print('end pose stage 2-4: ', pose) 
    
    print("end pose: ", pose)

devices = initialise_hardware.init()
nav = navigation.Navigation(devices)
cam = rpicam.Rpicam()
        
if USE_TELEMETRY:
    telemetry_client.connect()

devices['led'].all_off()
time.sleep(1)
devices['led'].yellow_on()
print("wait for button")
# display LED colour to show it is ready and the mode (obstacle or open)
while True:
    if devices["pi"].read(17) == 0:
        time.sleep(0.5)
        break 

devices['led'].yellow_off()

devices['lidar'].flush()
# pose = initialise_pose.obstacle_on_path(devices)
pose = initialise_pose.obstacle_in_parking(devices)
print('initial pose =', pose)

devices['led'].green_on()

park_func = ""

if pose[0] < 1500:
    red_paths = cw_obstacle_inner_paths
    green_paths = cw_obstacle_outer_paths
    inner_starting_paths = cw_obstacle_first_inner_paths
    outer_starting_paths = cw_obstacle_first_outer_paths
    parking_path = cw_parking_path
    obstacle_positions = cw_obstacle_positions
    park_func = "cw"
else:
    green_paths = ccw_obstacle_inner_paths
    red_paths = ccw_obstacle_outer_paths
    inner_starting_paths = ccw_obstacle_first_inner_paths
    outer_starting_paths = ccw_obstacle_first_outer_paths
    parking_path = ccw_parking_path
    obstacle_positions = ccw_obstacle_positions
    park_func = "ccw"

# Reverse if necessary 
# L_dist = min(get_distance(ldr, 20), get_distance(ldr, 25), get_distance(ldr, 30), get_distance(ldr, 35), get_distance(ldr, 40), get_distance(ldr, 45))
# R_dist = min(get_distance(ldr, 340), get_distance(ldr, 335), get_distance(ldr, 330), get_distance(ldr, 325), get_distance(ldr, 320), get_distance(ldr, 315))
# reverse = False
# print("L_dist: ",  L_dist)
# if pose[0] < 1500: #left
#     if R_dist < 400:
#         colour = rpicam.detect_blob()
#         if colour == "r":
#             reverse = True
#             print(colour)
#             paths = obstacle_inner_paths
#         else:
#             print(colour)
#             paths = obstacle_outer_paths
# else:
#     if L_dist < 400:
#         colour = rpicam.detect_blob()
#         if colour == "r":
#             reverse = True
#             print(colour)
#             paths = obstacle_outer_paths
#         else:
#             print(colour)
#             paths = obstacle_inner_paths

path_idx = 0 
# obstacle_position = obstacle_positions[path_idx]
# obstacle_position = obstacle_positions[-1]

# print("obstacle_position: ", obstacle_position)
# dir_to_obstacle = dir_to_point(pose, obstacle_position)
# print("dir_to_obstacle: ", dir_to_obstacle)
#devices["camera_servo"].set_dir(dir_to_obstacle)
#time.sleep(1)

# Main Loop
odometry.reset_pose()
print_period = 0.5
next_print = time.time() + print_period
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

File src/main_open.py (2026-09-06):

import time

import initialise_hardware as initialise_hardware
import initialise_pose as initialise_pose
import telemetry_client as telemetry_client
import sensors as sensors
import odometry as odometry
import point_cloud_localisation as localisation
import complementary_filter as complementary_filter
import navigation as navigation
import led as led
from paths import open_first_path, cw_paths, ccw_paths

USE_TELEMETRY = False
SPEED = 250 
PATHS_LIMIT = 4
SEGMENT_DIVIDER = 1700
STOPPING_TOP_POS = 1800
STOPPING_BOTTOM_POS = 1300

MODE = "obstacle"

devices = initialise_hardware.init()
nav = navigation.Navigation(devices)

if USE_TELEMETRY:
    telemetry_client.connect()

devices['led'].all_off()
time.sleep(1)
devices['led'].red_on()
print("wait for button")
# # display LED colour to show it is ready and the mode (obstacle or open)
while True:
    if devices["pi"].read(17) == 0:
        time.sleep(0.5)
        break 

devices['led'].red_off()

devices['lidar'].flush()
pose = initialise_pose.open(devices)
print('initial pose:', pose)
devices['led'].green_on()

# Check if first wall is extended 
if pose[3]:
    open_first_path[0][0] = 300
    open_first_path[1][0] = 300

# Save startin segment
segment = 'top'
if pose[1] < SEGMENT_DIVIDER:
    segment = 'bottom'

# --------------- First path --------------- # 
odometry.reset_pose()
while True:
    sensor_readings = sensors.read(devices)
    odometry_pose = odometry.estimate_pose(pose, sensor_readings)
    localised_pose = localisation.localise(odometry_pose, sensor_readings, MODE)
    if localised_pose: 
        # pose = complementary_filter.merge(odometry_pose, localised_pose)
        pose = odometry_pose
        print(f"odo_pose: {odometry_pose}, localised_pose: {localised_pose}")
#        print(pose)
    else:
        pose = odometry_pose

#    print(pose)
    if nav.drive_path(open_first_path, pose, SPEED):
        break

# ----- Change it such that the while loop only breaks after the pose is confirmed ----- #
print("Checking position")
while True:
    sensor_readings = sensors.read(devices)
    odometry_pose = odometry.estimate_pose(pose, sensor_readings)
    localised_pose = localisation.localise(odometry_pose, sensor_readings, MODE)
    if localised_pose: 
        print(pose)
        tmp_pose = initialise_pose.confirm_pose(pose, sensor_readings)
        if tmp_pose != None:
            pose = tmp_pose
            break
    pose = odometry_pose


paths = []
if pose[0] < 1500:
    paths = cw_paths
    print('cw')
else:
    paths = ccw_paths
    print('ccw')
path_idx = 1 # skip first path

print('After first path: ', pose)


# --------------- Main Loop --------------- # 
while True:
    sensor_readings = sensors.read(devices)
    odometry_pose = odometry.estimate_pose(pose, sensor_readings)
    localised_pose = localisation.localise(odometry_pose, sensor_readings, MODE)
    if localised_pose: 
        pose = complementary_filter.merge(odometry_pose, localised_pose)
        print('Localised pose: ', pose)
        # if abs(localised_pose[2] - odometry_pose[2]) > 9:
        #     break
    else:
        pose = odometry_pose
        
    
    path_changed, path_idx = nav.drive_paths(path_idx, paths, pose, SPEED)
    if path_changed:
        print('path_changed: ', path_idx)
    if path_idx >= PATHS_LIMIT:
        if segment == 'bottom' and pose[1] >= STOPPING_BOTTOM_POS:
            break
        elif segment == 'top' and pose[1] >= STOPPING_TOP_POS:
            break

nav.stop()

    

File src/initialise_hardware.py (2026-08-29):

import gyro as gyro 
import coind4 as coind4
import pigpio
import encoder as encoder
import drive as drive
import camera_servo as camera_servo
import led as led

BUTTON_PIN = 17 

def init():
    gyro_device = gyro.Gyro()
    gyro_device.load_calibration()

    lidar = coind4.CoinD4()
    lidar.start()

    pi = pigpio.pi()
    encoder_device = encoder.Encoder(pi)
    drive_device = drive.Drive(pi)
    camera_servo_device = camera_servo.CameraServo(pi)
    led_device = led.LED(pi)

    # Set pin 17 as input   
    pi.set_mode(BUTTON_PIN, pigpio.INPUT)

    # Optional: Set pull-up resistor for cleaner input
    pi.set_pull_up_down(BUTTON_PIN, pigpio.PUD_UP)
    
    return {
        "gyro": gyro_device,
        "lidar": lidar, 
        "encoder": encoder_device, 
        "drive": drive_device,
        "pi": pi,
        "camera_servo": camera_servo_device,
        "led": led_device
    }

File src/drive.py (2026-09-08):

STEER_MAX = 42
CENTER_US = 1425  # center microseconds
STEER_GAIN = 2

#GPIO20, GPIO21

class Drive:
    def __init__(self, pi):
        self.pi = pi
        pi.set_PWM_frequency(20, 200)

    def drive(self, speed): # 0-255
        if speed > 0:
            self.pi.set_PWM_dutycycle(21, 255-speed)
            self.pi.set_PWM_dutycycle(20, 255)
        else:
            self.pi.set_PWM_dutycycle(21, 255)
            self.pi.set_PWM_dutycycle(20, 255+speed)

    def steering(self, dir):
        if dir < -STEER_MAX:
            dir = -STEER_MAX
        elif dir > STEER_MAX:
            dir = STEER_MAX
        pulse_duration = CENTER_US + (375 / 45) * dir
        self.pi.set_servo_pulsewidth(23, pulse_duration)

    def steer_p(self, dir, curr_angle, speed, debug=False, gain=STEER_GAIN):
        while curr_angle - dir > 180:
            curr_angle -= 360
        while curr_angle - dir < -180:
            curr_angle += 360

        error = curr_angle - dir
        correction = error * gain 
        if debug:
            print('steering', correction)
        self.steering(correction)
        self.drive(speed)

    def steer_p_back(self, dir, curr_angle, speed):
        while curr_angle - dir > 180:
            curr_angle -= 360
        while curr_angle - dir < -180:
            curr_angle += 360

        error = curr_angle - dir
        gain = -2 
        correction = error * gain 
        self.steering(correction)
        self.drive(-speed) 

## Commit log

2026-05-31 Refactored open programme: find initial pose (check left and right distances on fixed points of top outer wall) and main while loop
    [initialise_pose.py, main_open.py, navigation.py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]
2026-06-28 Tested and fixed point cloud localisation
    [point_cloud_localisation.py, point_cloud_test.py]
2026-07-12 calibrated MM_PER_STEPS
2026-07-12 Tested open: Left and Right distances [Success], check CW or CCW [Failed]
    [initialise_pose.py, main_open.py]
2026-07-12 test gyro
2026-08-02 1. enable_open and enable_obstacle to change programs 2. run stop.py after main.py completes in initialiser.sh 3. turn on led to indicate when bot is ready 4. main_sleep.py to disable initialiser 5. 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
2026-08-02 obstacle servo (unfinished)
2026-08-02 Refactor distance extraction and improve obstacle detection; update LED control in main scripts; add sleep script and adjust paths.
2026-08-16 - implemented flush function to clear lidar buffer - navigation uses point cloud localisation now
2026-08-16 - fixed dir_to_point - changed obstacle paths - fixed obstacle position assignment
    [coind4.py, initialise_hardware.py, initialise_pose.py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]
2026-08-19 upload all cad files
    [5.4mm_spacer.stl, ackerman_beam.dxf, ackerman_inverted_inside_beam.dxf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]
2026-08-22 software documentation - camera tracking
2026-08-22 models documentation + rpicam software documentation
    [2026_base_plate.dxf, 2026_level_plate.dxf, ackermann_beam.dxf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]
2026-08-23 added counterclockwise paths and obstacle positions, fixed lidar flush function
    [coind4.py, drive.py, main_obstacle.py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]
2026-08-23 PCB Images
2026-08-26 Fixed application of transformation matrix in ICP
    [point_cloud_localisation.py]
2026-08-29 inserted the images for the models
2026-08-31 fixed lidar flush function, increased merge ratio for localised_pose
    [coind4.py, complementary_filter.py, main_open.py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]
2026-09-05 improved lidar flush function, changed complementary filter ratio, fixed exiting parking maneuver, changed path gain and max_angle for navigation, added untested parking code, modified paths for obst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
    [coind4.py, complementary_filter.py, drive.py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]
2026-09-05 shift paths towards centre to avoid parking zone
    [paths.py]
2026-09-06 fixed bug in localise function
    [point_cloud_localisation.py]
2026-09-06 fixed ICP vertical wall matching
    [point_cloud_localisation.py]
2026-09-08 bugs fixes - ICP, odometry
    [main_obstacle_parking_test.py, odometry.py, point_cloud_localisation.py]
2026-10-24 increased maximum steering angle
